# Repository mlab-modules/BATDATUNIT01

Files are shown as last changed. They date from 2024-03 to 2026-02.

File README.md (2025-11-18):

# BATDATUNIT01 - Power and Data Storage Module

The BATDATUNIT01 is power and data storage module incorporating an ATmea1284p microcontroller paired with a five 18650 Li-ion safely rechargable accumulator cells. It is a reliable power source for extended durations, making it an integral component in various detectors or measuring systems.

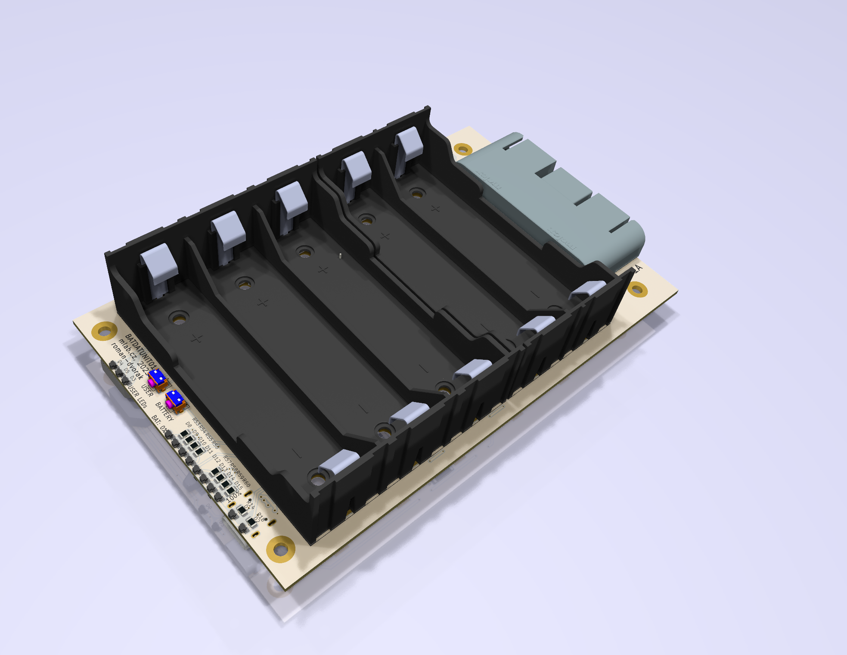
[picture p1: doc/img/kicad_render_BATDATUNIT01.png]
Previw of BATDATUNIT01 PCB


## Features

- **Microcontroller**: [ATmega1284p](https://www.microchip.com/wwwproducts/en/ATmega1284p) provides robust processing capabilities to manage complex tasks efficiently.
- **Battery Pack**: A Set of up to five Li-ion batteries offers substantial power, facilitating long-term operations without frequent recharging.
- **USB-C Charging**: Enables hassle-free charging with a USB-C interface, ensuring the module is readily powered for sustained use.
- **Charging and Monitoring Circuits**: The [BQ25628E](https://www.ti.com/product/BQ25628) circuit oversees the charging, while the [BQ34Z100](https://www.ti.com/product/BQ34Z100) gauge monitors the battery state for optimal energy management.

## Applications

The BATDATUNIT01 is designed for versatility:

- As a **power module for semiconductor particle detectors** like the [AIRDOS04](https://github.com/UniversalScientificTechnologies/AIRDOS04), it ensures uninterrupted data acquisition in environmental monitoring.
- It can be integrated into **remote sensing stations**, providing consistent power and data logging capabilities for long-term ecological studies.
- In **automated weather stations**, the module's resilience and sensor suite offers valuable insights into meteorological conditions.
- The module can be deployed in **mobile robotics** for energy supply and environmental data collection, aiding navigation and decision-making processes.
- It is also ideal for **educational purposes**, as a hands-on tool to teach about energy management, data acquisition, and sensor integration.

The robust design and connectivity options make the BATDATUNIT01 a dependable choice for powering and managing data across many scientific applications.

For more detailed information on interfacing and protocols, please refer to the [ATmea1284p datasheet](https://ww1.microchip.com/downloads/en/DeviceDoc/doc8059.pdf) and the communication standards for [UART](https://en.wikipedia.org/wiki/Universal_asynchronous_receiver-transmitter), [I2C](https://www.i2c-bus.org/), [SPI](https://en.wikipedia.org/wiki/Serial_Peripheral_Interface), and [GPIO](https://en.wikipedia.org/wiki/General-purpose_input/output).

## Design

Designed for convenience, the module allows for fast detachment from the measuring part without tools, streamlining the replacement process. Data can be downloaded during battery charging thanks to onboard memory.

BATDATAUNIT01 top view

BATDATAUNIT01 bottom view

## Schematics



### Internal structure

```mermaid

    flowchart TD

    subgraph a[User interfaceI]
        USB[[USB-C\nData + power]]
        UI1([User interface \n Button + battery indicator])
        UI2([User interface \n Button + 3x LED])
    
    end

    USB --USB --> USW

    FTDI -- I2C --> I2CSW
    FTDI -- UART <--> MCU
    MCU -- I2C --> I2CSW[I2C mux]
    MCU[Microcontroller]
    MCU --SPI <--> SDW
    MCU --> SDW

    subgraph one[Memory interface]
    SDR[SD card] <--> SDI
    SDI[SD card interface] -- USB <--> USW
    USW[USB-SWITCH]
    SDW[SD card \n SPI-SWITCH] <--> SDI
    end

    subgraph three[Digital part ]
    USW -- USB <--> FTDI[FTDI\nI2C + UART]

    I2CSW --I2C--> HYG[Hygrometer]
    I2CSW --I2C--> ALT[Pressure sensor]

    I2CSW -- I2C --> I2Cen

    end

    I2CSW --I2C--> GAUGE
    I2CSW --I2C--> charger

    GAUGE --> UI1
    MCU --> UI2

    GAUGE --> PWR3v3
    GAUGE --> PWR3v3E
    GAUGE --> PWR5vE
    
    USB -- Power --> charger

    subgraph two[POWER sources]
    PWR3v3[Power supply\nfor internal 3.3V]
    PWR3v3E[Power supply\nfor detector 3.3V]
    PWR5vE[Power supply\nfor detector 5V]
    
    charger --> GAUGE[Accumulators gauge]
    GAUGE <==> LIION[(5x Li-ion cells)]
    end
    PWR3v3 --> MCU

    PWR3v3E --> DI
    PWR5vE --> DI

    I2Cen[I2C switch] -- I2C --> DI
    DI[[Detector interface]] == GPIO, SPI <==> MCU

```

## Connectivity

A durable Molex connector brings together data and detection with impressive mechanical resilience. It hosts UART, I2C, SPI buses, and extra GPIO signals, providing extensive interfacing options with various systems. The complementary module to the interface connector is [BATDATSOCKET01](https://github.com/mlab-modules/BATDATSOCKET01).

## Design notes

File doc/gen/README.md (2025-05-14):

# PCB

Board size: 136.15x85.85 mm (5.36x3.38 inches)

- This is the size of the rectangle that contains the board
- Thickness: 1.6 mm (63 mils)
- Material: FR4
- Finish: None
- Layers: 2
- Copper thickness: 35 µm

Solder mask: TOP / BOTTOM

- Color: Green

Silk screen: TOP / BOTTOM

- Color: White

Stackup:

| Name | Type | Color | Thickness [µm]| Material | Er | Loss tan |
|---|---|---|---|---|---|---|
| F.SilkS | Top Silk Screen | White | | | | |
| F.Paste | Top Solder Paste | | | | | |
| F.Mask | Top Solder Mask | Green | 10 | | | |
| F.Cu | copper | | 35 | | | |
| dielectric 1 | core | FR4 natural | 1510 | FR4 | 4.5 | 0.020 |
| B.Cu | copper | | 35 | | | |
| B.Mask | Bottom Solder Mask | Green | 10 | | | |
| B.Paste | Bottom Solder Paste  | | | | | |
| B.SilkS | Bottom Silk Screen | White | | | | |

# Important sizes

Clearance: 0.2 mm (8 mils)

Track width: 0.2 mm (8 mils)

- By design rules: 0.0 mm (0 mils)

Drill: 0.4 mm (16 mils)

- Vias: 0.4 mm (16 mils) [Design: 0.35 mm (14 mils)]
- Pads: 0.6 mm (24 mils)
- The above values are real drill sizes, they add 0.1 mm (4 mils) to plated holes (PTH)

Via: 0.5/0.3 mm (20/12 mils)

- By design rules: 0.5/0.25 mm (20/10 mils)
- Micro via: yes [0.2/0.1 mm (8/4 mils)]
- Buried/blind via: yes
- Total: 415 (thru: 415 buried/blind: 0 micro: 0)

Outer Annular Ring: 0.05 mm (2 mils)

- By design rules: 0.05 mm (2 mils)

Eurocircuits class: 6D
- Using min drill 0.25 mm for an OAR of 0.13 mm

# General stats

Components count: (SMD/THT)

- Top: 27/7 (SMD + THT)
- Bottom: 173/3 (SMD + THT)

Defined tracks:

- 0.2 mm (8 mils)
- 0.3 mm (12 mils)
- 0.4 mm (16 mils)
- 0.5 mm (20 mils)

Used tracks:

- 0.2 mm (8 mils) (136) defined: yes
- 0.25 mm (10 mils) (68) defined: no
- 0.3 mm (12 mils) (1377) defined: yes
- 0.4 mm (16 mils) (136) defined: yes
- 0.5 mm (20 mils) (55) defined: yes
- 0.8 mm (31 mils) (38) defined: no
- 0.9 mm (35 mils) (19) defined: no
- 1.0 mm (39 mils) (31) defined: no
- 1.5 mm (59 mils) (3) defined: no

Defined vias:

- 0.5/0.3 mm (20/12 mils)
- 0.8/0.4 mm (31/16 mils)

Used vias:

- 0.5/0.3 mm (20/12 mils) (Count: 257, Aspect: 3.2 A) defined: yes
- 0.8/0.4 mm (31/16 mils) (Count: 158, Aspect: 2.0 A) defined: yes

Holes (excluding vias):

- 0.65 mm (26 mils) (2)
- 0.75 mm (30 mils) (30)
- 1.02 mm (40 mils) (40)
- 1.6 mm (63 mils) (10)
- 3.0 mm (118 mils) (4)
- 3.2 mm (126 mils) (12)

Oval holes:

- 0.5x0.9 mm (20x35 mils) (4)
- 0.6x1.4 mm (24x55 mils) (2)
- 0.6x1.7 mm (24x67 mils) (2)

Drill tools (including vias and computing adjusts and rounding):

- 0.4 mm (16 mils) (257)
- 0.5 mm (20 mils) (158)
- 0.6 mm (24 mils) (4)
- 0.65 mm (26 mils) (2)
- 0.7 mm (28 mils) (4)
- 0.85 mm (33 mils) (30)
- 1.1 mm (43 mils) (40)
- 1.7 mm (67 mils) (10)
- 3.1 mm (122 mils) (4)
- 3.2 mm (126 mils) (12)

Solder paste stats:

Using a paste with 87.75 % alloy, that has an specific gravity for the alloy of 7.4 g/cm³
and 1.0 g/cm³ for the flux. This paste has an specific gravity of  4.15 g/cm³.

The stencil thickness is  0.12 mm.

| Side | Pads with paste | Area [mm²] | Paste [g] |
|---|---|---|---|
| Top | 60 | 68.31 | 0.34 |
| Bottom | 640 | 831.67 | 4.14 |
| Total  | 700 | 899.98 | 4.48 |

Note: this is just an approximation to the theoretical value. Margins of the solder mask and waste aren't computed.

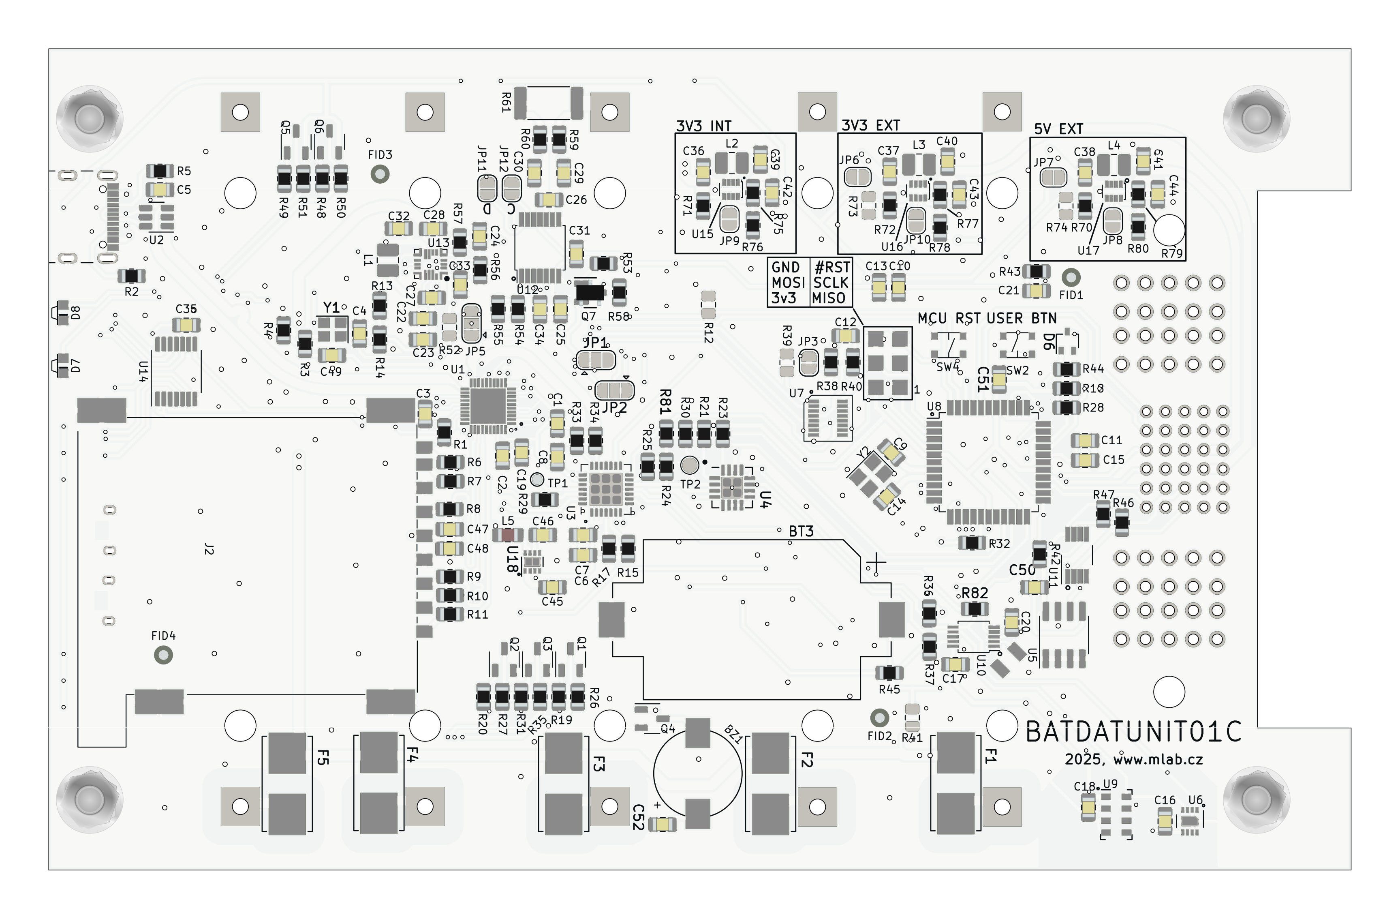
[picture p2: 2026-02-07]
doc/gen/img/BATDATUNIT01-bottom.png

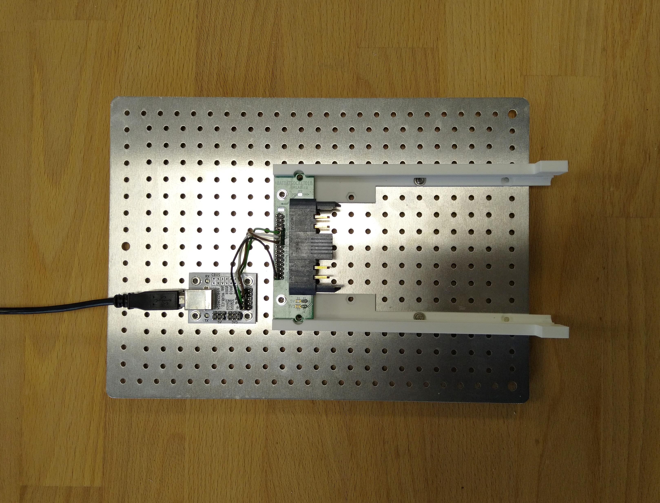
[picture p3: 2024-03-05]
doc/img/BATDATUNIT01_programming_device.jpg

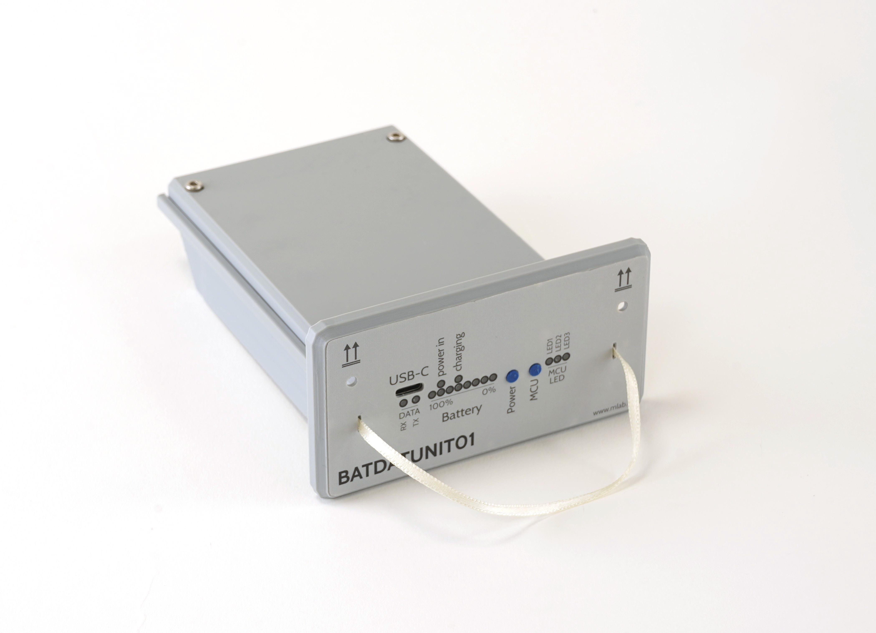
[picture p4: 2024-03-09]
doc/img/BATDATUNIT01.jpg

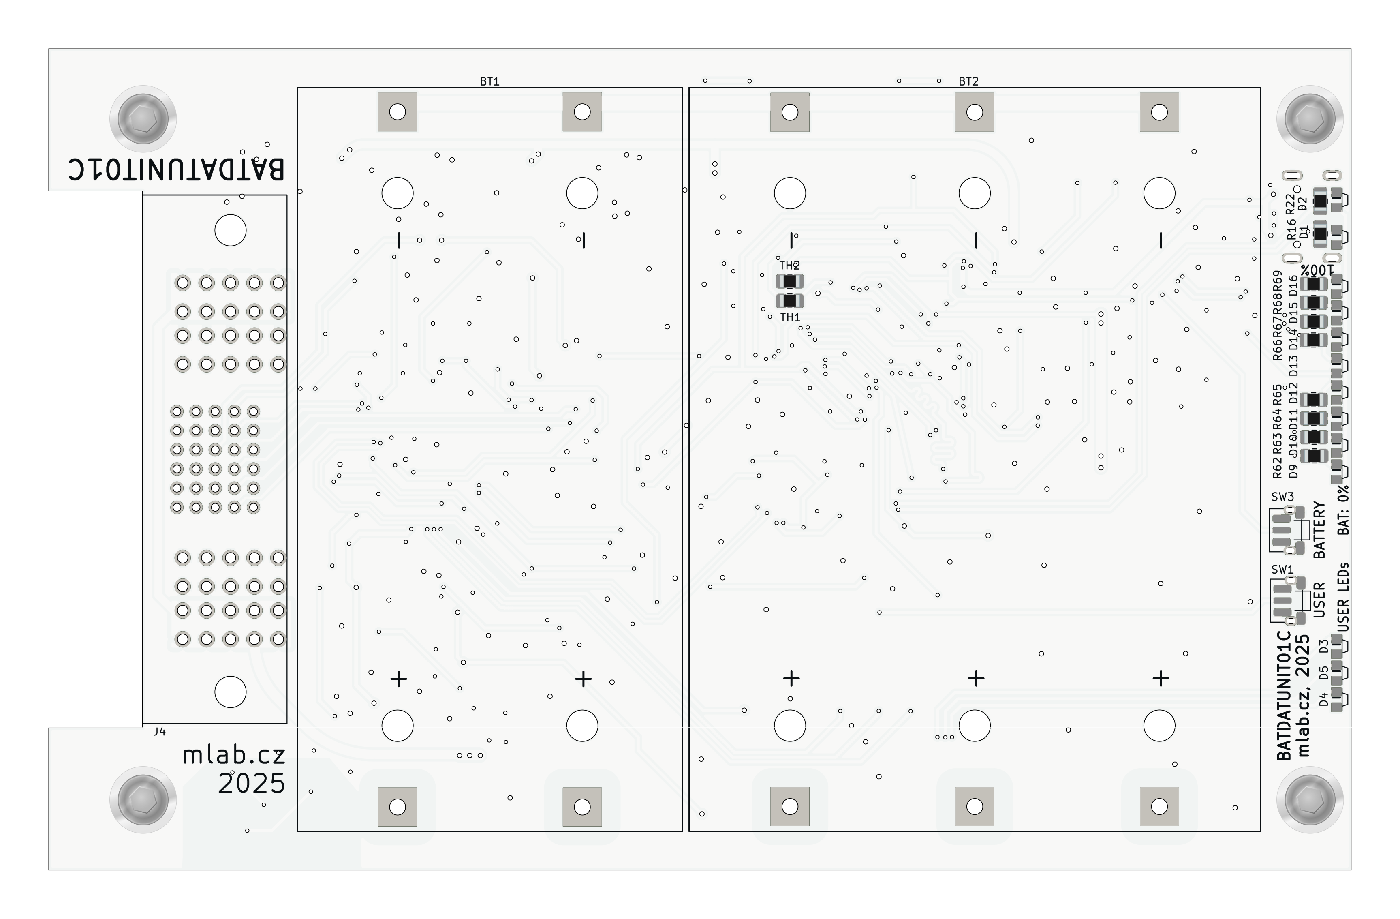
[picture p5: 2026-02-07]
doc/gen/img/BATDATUNIT01-top.png

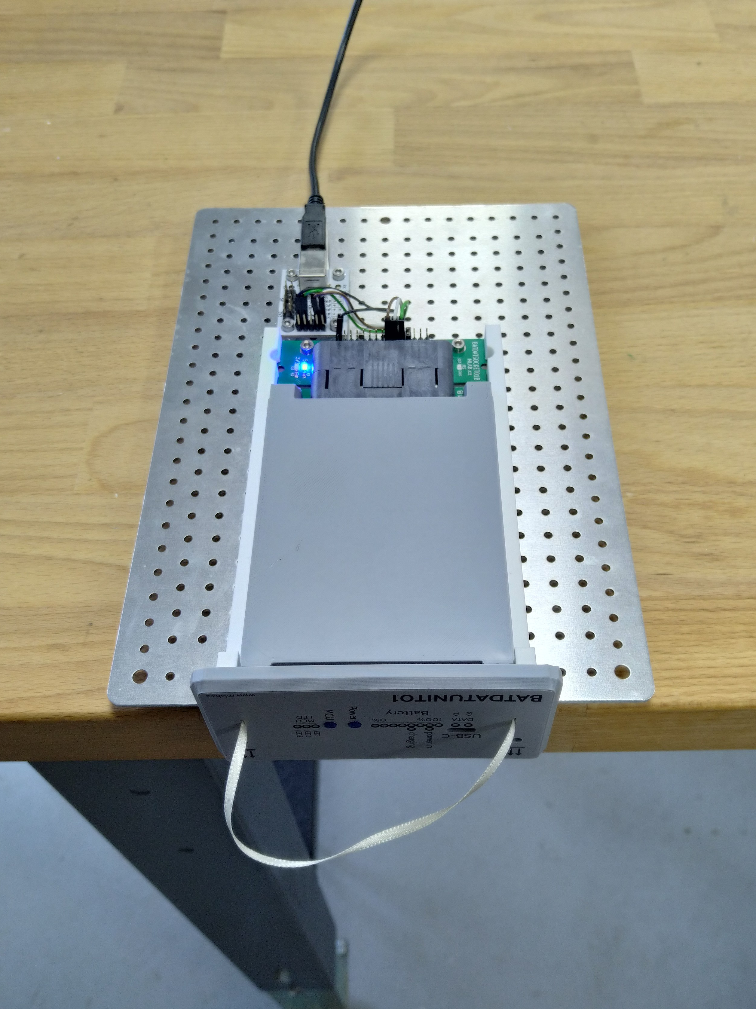
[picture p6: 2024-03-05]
doc/img/BATDATUNIT01_programming.jpg

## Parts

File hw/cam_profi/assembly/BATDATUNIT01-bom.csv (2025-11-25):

Component | Description | Part | References | Value | Footprint | Quantity Per PCB | Datasheet | ust_id | mfpn | mpn | sim.device | sim.type | sim.pins | height | i2c | manufacturer_name | manufacturer_part_number | mouser part number | mouser price/stock | arrow part number | arrow price/stock | lcsc
1 | Single-cell battery | 2xBATT | BT1 | BATT | BAT_BK-18650-PC4 | 1 | ~ | 5c70984412875079b91f87e9
2 | Single-cell battery | 3xBATT | BT2 | BATT | BAT_BK-18650-PC6 | 1 | ~ | 63567f66c8e7b5bbef872ce1
3 | Single-cell battery | Battery_Cell | BT3 | CR2032 | BatteryHolder_Keystone_1060_1x2032 | 1 | ~ | 68249eacee7fc534862c6977
4 | Buzzer, polarized | Buzzer | BZ1 | LET9032ES-03L | MagneticBuzzer_LET9032ES-03L-2.7-16-R | 1 | https://www.cre-soundbuzzer.com/datasheet/LET9032ES-03L-2.7-16-R.pdf | 5fa0f13812875025b3977890
5 | Unpolarized capacitor, small symbol | C_Small | C9C14 | 15p | C_0805_2012Metric | 2 | ~ | 5c70984712875079b91f8b32
6 | Unpolarized capacitor, small symbol | C_Small | C5C46 | 1n | C_0805_2012Metric | 2 | ~ | 5c70984712875079b91f8b45 | C0805 1u | C0805 1u
7 | Unpolarized capacitor, small symbol | C_Small | C34 | 3n3 | C_0805_2012Metric | 1 | ~ | 5c70984712875079b91f8b47
8 | Unpolarized capacitor, small symbol | C_Small | C27 | 47n | C_0805_2012Metric | 1 | ~ | 65482046462c6d9e72056b98
9 | Unpolarized capacitor, small symbol | C_Small | C1C2C3C4C6C8C10C13C15C16C17C18C20C23C25C26C29C30C35C48C49C50C51C52 | 100n | C_0805_2012Metric | 24 | ~ | 5c70984712875079b91f8b4c
10 | Unpolarized capacitor, small symbol | C_Small | C19C24C31C45 | 1u | C_0805_2012Metric | 4 | ~ | 5c70984712875079b91f8b50
11 | Unpolarized capacitor, small symbol | C_Small | C7C12C33 | 4u7 | C_0805_2012Metric | 3 | ~ | 5c70984712875079b91f8b52
12 | Unpolarized capacitor, small symbol | C_Small | C11C22C28C42C43C44C47 | 10u | C_0805_2012Metric | 7 | ~ | 5c70984712875079b91f8b53
13 | Unpolarized capacitor, small symbol | C_Small | C21C32C36C37C38 | 22u | C_0805_2012Metric | 5 | ~ | 650b58f1462c6d9e7205463b
14 | Unpolarized capacitor, small symbol | C_Small | C39C40C41 | 47u | C_0805_2012Metric | 3 | ~ | 5c70984812875079b91f8bbf
15 | 100V, 0.175A, High-speed Switching Diode, SOT-323 | BAS16W | D6 | BAS16W | SOT-323_SC-70 | 1 | https://assets.nexperia.com/documents/data-sheet/BAS16_SER.pdf | 5c70984512875079b91f88af
16 | Light emitting diode, small symbol | LED_Small | D3D8D13D14D15D16 | GREEN | SMD_LED_RIGHT_KINGBRIGHT_1605 | 6 | ~ | 65481f0c462c6d9e72056b3d
17 | Light emitting diode | LED | D2 | GREEN | SMD_LED_RIGHT_KINGBRIGHT_1605 | 1 | https://cz.mouser.com/datasheet/2/216/APA1606SGC-76546.pdf | 65481f0c462c6d9e72056b3d
18 | Light emitting diode, small symbol | LED_Small | D4D7D11D12 | ORANGE | SMD_LED_RIGHT_KINGBRIGHT_1605 | 4 | ~ | 65481fdd462c6d9e72056b6a
19 | Light emitting diode | LED | D1 | RED | SMD_LED_RIGHT_KINGBRIGHT_1605 | 1 | https://cz.mouser.com/datasheet/2/216/APA1606SURCK-63848.pdf | 65481f96462c6d9e72056b54
20 | Light emitting diode, small symbol | LED_Small | D5D9D10 | RED | SMD_LED_RIGHT_KINGBRIGHT_1605 | 3 | ~ | 65481f96462c6d9e72056b54
21 | Fuse | Fuse | F1F2F3F4F5 | Fuse | Fuseholder_Littelfuse_Nano2_154x | 5 | https://cz.mouser.com/datasheet/2/240/media-3321028.pdf | 5c70984512875079b91f88d8
22 |  | MOLEX_46436-9327 | J4 | 46436-9327 | MOLEX_46436-9327 | 1 |  | 65481d4a462c6d9e72056b06
23 | 2x03 2.54 mm pitch header | HEADER_2x03 | J3 | HEADER_2x03 | SMD_2x03 | 1 |  | x
24 |  | SD_Card-FPS009-4200-0 | J2 | SD_Card-FPS009-4200-0 | FPS009-4200-0 | 1 |  | 5cdd24d5128750448edda353
25 | USB 2.0-only Type-C Receptacle connector | USBC_USB4105-GF-A | J1 | USBC_USB4105-GF-A | USBC GCT_USB4105-GF-A | 1 |  | 5fa0f94612875025b397795e | USB4105-GF-A | USB4105-GF-A
26 | Jumper, 2-pole, open | Jumper_2_Open | JP6JP7JP8JP9JP10JP11JP12 | Jumper_2_Open | SolderJumper-2_P1.3mm_Open_RoundedPad1.0x1.5mm | 7 | ~ | x
27 | Inductor | L | L5 | 100uH | L_0805_2012Metric_Pad1.15x1.40mm_HandSolder | 1 | ~ | 626fd6fcdc56076e9a222966
28 | Inductor | L | L1L2L3L4 | 1uH - DFE252012P-1R0M=P2 | L_1008_2520Metric | 4 | ~ | 650b5977462c6d9e72054656
29 | PNP transistor, base/emitter/collector | Q_PNP_BEC | Q5Q6 | BC807-25 | SOT-23-3 | 2 | ~ | 5c70984712875079b91f8aeb |  |  | NPN | GUMMELPOON | 1=C 2=B 3=E
30 | NPN transistor, base/emitter/collector | Q_NPN_BEC | Q1Q2Q3Q4 | BC817-25 | SOT-23-3 | 4 | ~ | 5c70984712875079b91f8aea |  |  | NPN | GUMMELPOON | 1=C 2=B 3=E
31 | P-MOSFET transistor, gate/source/drain | Q_PMOS_GSD | Q7 | BSS83P | SOT-23 | 1 | ~ | 5c70984712875079b91f8ae6
32 | Resistor, small symbol | R_Small | R33R34 | 33R | R_0805_2012Metric | 2 | ~ | 5c70984512875079b91f8970
33 | Resistor, small symbol | R_Small | R22R26R51R66R67R68R69 | 68R | R_0805_2012Metric | 7 | ~ | 5c70984512875079b91f8975
34 |  | R-device-DATALOGGER01A-rescue-CCP2019V01A-rescue-SPACEDOS01A_PCB01A-rescue-SPACEDOS01B_PCB01A-rescue | R6R7R8R9R10R11R38R82 | 100R | R_0805_2012Metric | 8 |  | 5c70984512875079b91f8977
35 | Resistor, small symbol | R_Small | R59R60 | 100R | R_0805_2012Metric | 2 | ~ | 5c70984512875079b91f8977
36 | Resistor, small symbol | R_Small | R16R27R35R50R54R62R63R64R65 | 270R | R_0805_2012Metric | 9 | ~ | 5c70984512875079b91f8983
37 | Resistor, small symbol | R_Small | R53 | 510R | R_0805_2012Metric | 1 | ~ | 5c70984512875079b91f8988
38 | Resistor, small symbol | R_Small | R15R17R19R20R31R32R48R49R55 | 1k | R_0805_2012Metric | 9 | ~ | 5c70984512875079b91f898c
39 | Resistor, small symbol | R_Small | R56 | 2k4 | R_0805_2012Metric | 1 | ~ | 5c70984612875079b91f8991
40 | Resistor, small symbol | R_Small | R2R4R5R29R57 | 5k1 | R_0805_2012Metric | 5 | ~ | 5fa0fc3e12875025b3977997
41 | Resistor, small symbol | R_Small | R1 | 6.19k | R_0805_2012Metric | 1 | ~ | 6548142e462c6d9e72056976
42 | Resistor, small symbol | R_Small | R3R18R21R23R24R25R28R30R36R37R40R42R44R46R47R70R72R81 | 10k | R_0805_2012Metric | 18 | ~ | 5c70984612875079b91f899f
43 | Resistor, small symbol | R_Small | R14 | 25k5 | R_0805_2012Metric | 1 | ~ | 5c70984712875079b91f8a88
44 | Resistor, small symbol | R_Small | R58 | 33k | R_0805_2012Metric | 1 | ~ | 5c70984712875079b91f8a8a
45 | Resistor, small symbol | R_Small | R13 | 68k | R_0805_2012Metric | 1 | ~ | 5c70984712875079b91f8a91
46 | Resistor, small symbol | R_Small | R76R78R80 | 91k | R_0805_2012Metric | 3 | ~ | 5c70984712875079b91f8a95
47 | Resistor, small symbol | R_Small | R43 | 270k | R_0805_2012Metric | 1 | ~ | 5c70984712875079b91f8aa0
48 | Resistor, small symbol | R_Small | R75R77 | 511k | R_0805_2012Metric | 2 | ~ | 650b5a43462c6d9e7205468e
49 | Resistor, small symbol | R_Small | R79 | 806k | R_0805_2012Metric | 1 | ~ | 650b5abb462c6d9e720546b8
50 | Resistor, small symbol | R_Small | R61 | 0R01 75PPM | R_2512_6332Metric | 1 | ~ | 5c70984712875079b91f8abf
51 | Push button switch, generic, two pins | SW_Push | SW2SW4 | KMT031 | KMT031 NGJ LHS C&K | 2 | ~ | 612515a61287500165a9771d
52 | Push button switch, generic, two pins | SW_Push_shield | SW1SW3 | SKRTLAE010 | SKRT | 2 | ~ | 65481517462c6d9e720569b4
53 | Temperature dependent resistor | Thermistor | TH1 | 10k NTC | R_0805_2012Metric | 1 | ~ | 5c70984712875079b91f8ac5
54 | Temperature dependent resistor, negative temperature coefficient | Thermistor_NTC | TH2 | 10k NTC | R_0805_2012Metric | 1 | ~ | 5c70984712875079b91f8ac5
55 | I2C Serial EEPROM, 64Kb (8192x8) with Unique Serial Number, SO8 | AT24CS64-SSHM | U5 | AT24CS64-SSHM | SOIC-8_3.9x4.9mm_P1.27mm | 1 | http://ww1.microchip.com/downloads/en/DeviceDoc/Atmel-8870-SEEPROM-AT24CS64-Datasheet.pdf | 5c70984712875079b91f8b99 |  |  |  |  |  | 1.5
56 | 20MHz, 128kB Flash, 16kB SRAM, 4kB EEPROM, JTAG, TQFP-44 | ATmega1284P-A | U8 | ATMEGA1284P-AU | TQFP-44_10x10mm_P0.8mm | 1 | http://www.atmel.com/Images/Atmel-8272-8-bit-AVR-microcontroller-ATmega164A_PA-324A_PA-644A_PA-1284_P_datasheet.pdf | 5c70984412875079b91f888e |  |  |  |  |  | 1.1
57 | BQ25628E I2C Controlled 1-Cell, 2-A, Maximum 18-V Input, Buck Battery Charger with NVDC Power Path Management | BQ25628E | U13 | BQ25628E | Texas_S-WQFN-HR-18 | 1 | https://www.ti.com/lit/ds/symlink/bq25628e.pdf | 65481a71462c6d9e72056aa4 |  |  |  |  |  |  | 0x6B
58 |  | BQ34Z100 | U12 | BQ34Z100 | TSSOP-14_4.4x5mm_Pitch0.65mm | 1 | https://www.ti.com/lit/ds/symlink/bq34z100-g1.pdf | 5c70984612875079b91f89c3 |  |  |  |  |  | 1,2 | 0xAA
59 | USB HID to UART/I2C Bridge WQFN-28 Tray FTDI Chip FT260Q-T, USB Controller, 3.4MBps, HID, I2C, UART, USB 2.0, 1.8 V, 2.5 V, 3.3 V, 5 V, 28-Pin WQFN | FT260Q-T | U3 | FT260Q-T | QFN-28-1EP_5x5mm_P0.5mm_EP3.35x3.35mm | 1 | http://www.ftdichip.com/Support/Documents/DataSheets/ICs/DS_FT260.pdf | 65481702462c6d9e72056a21 |  |  |  |  |  | 0.8 |  | FTDI Chip | FT260Q-T | 895-FT260Q-T | https://www.mouser.co.uk/ProductDetail/FTDI/FT260Q-T?qs=b3QwWlrdtstFEkgcxHO4EA%3D%3D | FT260Q-T | https://www.arrow.com/en/products/ft260q-t/ftdi-chip?region=nac
60 | Hi-Speed USB-to-SD Card Readers with Bypass | MAX14502AETL+ | U1 | MAX14502AETL+ | QFN40P500X500X80-41N | 1 | https://datasheet.octopart.com/MAX14502AETL%2B-Dallas-Semiconductor-datasheet-13718882.pdf | 6548165f462c6d9e720569f7 |  |  |  |  |  | 0.8 | 0x71 | Analog Devices | MAX14502AETL+
61 | Sensor Pressure 1.2bar Barometric SMD MS561101BA03-50, Barometric Pressure Sensor, 1200mbar 0 3.6 V Output, 8-Pin QFN | MS561101BA03-50 | U9 | MS561101BA03-50 | LGA-8_3x5mm_P1.25mm | 1 | https://cz.mouser.com/datasheet/2/418/6/ENG_DS_MS5611_01BA03_B3-1134567.pdf | 650b36b0462c6d9e720543f4 |  |  |  |  |  | 1 | 0x76 | TE Connectivity | MS561101BA03-50 | 824-MS561101BA03-50 | https://www.mouser.co.uk/ProductDetail/Measurement-Specialties/MS561101BA03-50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
62 | I/O Controller Interface IC 2-to-1 I2C-bus master selector | PCA9541ABS_03,118 | U4 | PCA9541ABS/01 | QFN-16-1EP_4x4mm_P0.65mm_EP2.15x2.15mm | 1 | http://www.nxp.com/docs/en/data-sheet/PCA9541A.pdf | 65481909462c6d9e72056a4a |  |  |  |  |  | 1 | 0x70 | NXP | PCA9541ABS/03,118 | 771-PCA9541ABS03,118 | https://www.mouser.co.uk/ProductDetail/NXP-Semiconductors/PCA9541ABS-03118?qs=zgUyOPfUqsKSEeCPg1WHUw%3D%3D
63 | RTC | PCF85263A | U10 | PCF85263A | TSSOP-10_3x3mm_P0.5mm | 1 | https://www.nxp.com/docs/en/data-sheet/PCF85263A.pdf | 5c70984612875079b91f8a0c |  |  |  |  |  | 1.1 | 0x
64 | I²C humidity and temperature sensor, ±1.5%RH, ±0.1°C, DFN-8 | SHT35-DIS | U6 | SHT31-DIS | Sensirion_DFN-8-1EP_2.5x2.5mm_P0.5mm_EP1.1x1.7mm | 1 | https://sensirion.com/media/documents/213E6A3B/63A5A569/Datasheet_SHT3x_DIS.pdf | 5c70984612875079b91f89e4 |  |  |  |  |  | 0.9 | 0x44
65 |  | SN74HC164D | U14 | SN74HC164P | TSSOP-14_4.4x5mm_P0.65mm | 1 | https://www.ti.com/lit/ds/symlink/sn74hc164.pdf | 6559399f95a79cc5ac40a0a6
66 |  | TCA4307 | U11 | TCA4307 | VSSOP-8_3.0x3.0mm_P0.65mm | 1 | https://www.ti.com/lit/ds/symlink/tca4307.pdf?ts=1617607418171 | 6087a3f3128750769ee58f03
67 | Analogue Switch ICs Low-capacitance, 2:1 (SPDT) 4-channel, powered-off protection switch with 1.8-V logic 16-SOT-23-THN -40 to 125 | TMUX1574DYYR | U7 | TMUX1574DYYR | SOT-23-16 THIN | 1 | https://www.ti.com/lit/gpn/TMUX1574 | 65481983462c6d9e72056a6d |  |  |  |  |  | 1.1 |  | Texas Instruments | TMUX1574DYYR | 595-TMUX1574DYYR | https://www.mouser.co.uk/ProductDetail/Texas-Instruments/TMUX1574DYYR?qs=B6kkDfuK7%2FDgs0e8M6dtlw%3D%3D | TMUX1574DYYR | https://www.arrow.com/en/products/tmux1574dyyr/texas-instruments?region=nac
68 |  | TPS22965-Q1-MLAB_IO | U18 | TPS22965-Q1 | WSON-8-1EP_2x2mm_P0.5mm_EP0.9x1.6mm | 1 | https://www.ti.com/lit/ds/symlink/tps22965-q1.pdf | 5c70984712875079b91f8b78
69 | Switching Voltage Regulators 1.5-A output current, high power density buck-boost converter | TPS631000DRLR | U15U16U17 | TPS631000DRLR | SOT-583-8 | 3 | https://www.ti.com/lit/ds/symlink/tps631000.pdf?ts=1652152702265 | 63de5ae4ae0b2d5aa05e2714 |  |  |  |  |  | 0.5 |  | Texas Instruments | TPS631000DRLR | 595-TPS631000DRLR | https://www.mouser.co.uk/ProductDetail/Texas-Instruments/TPS631000DRLR?qs=rSMjJ%252B1ewcRYwoN2deTeNA%3D%3D
70 | Very low capacitance ESD protection diode, 2 data-line, SOT-23-6 | USBLC6-2SC6 | U2 | USBLC6-2SC6 | SOT-23-6 | 1 | https://www.st.com/resource/en/datasheet/usblc6-2.pdf | 5e82e0691287502a334a778c |  |  |  |  |  |  |  |  |  |  |  |  |  | C7519
71 | Crystal Clock Oscillator, | CXO_DIP8 | Y1 | 19.2 MHz | Crystal_SMD_2520-4Pin_2.5x2.0mm | 1 |  | 67f16090ee7fc534862c5860
72 | Four pin crystal, GND on pins 2 and 4, small symbol | Crystal_GND24_Small | Y2 | 8 MHz | Crystal_SMD_3225-4Pin_3.2x2.5mm | 1 | ~ | 65481c4c462c6d9e72056ac8
73 |  | Crystal-device-DATALOGGER01A-rescue-CCP2019V01A-rescue | Y3 | ABS07-120-32.768KHZ-T | ABS07 | 1 |  | 5c70984712875079b91f8b1b

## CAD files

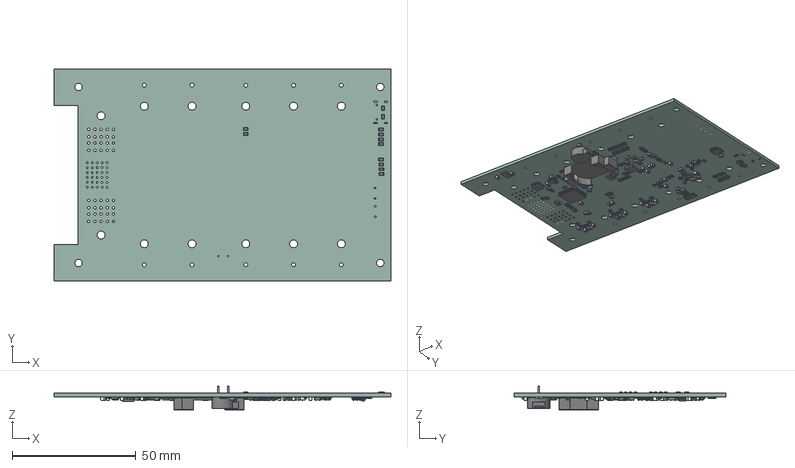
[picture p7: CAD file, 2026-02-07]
doc/gen/BATDATUNIT01.step
136.2 x 85.9 x 9.68 mm
R_0805_2012Metric x 77
LGA-8_3x5mm_P1.25mm
C_0805_2012Metric x 52
SOT-23-3 x 4
SOT-23 x 7
L_1008_2520Metric x 4
SOT-583-8 x 3
SOT-23-6
R_2512_6332Metric
BatteryHolder_Keystone_1060_1x2032
QFN-16-1EP_4x4mm_P0.65mm_EP2.15x2.15mm
L_0805_2012Metric
Crystal_SMD_3225-4Pin_3.2x2.5mm
WSON-8-1EP_2x2mm_P0.5mm_EP0.9x1.6mm
SOIC-8_3.9x4.9mm_P1.27mm
QFN-28-1EP_5x5mm_P0.5mm_EP3.35x3.35mm
SOT-323_SC-70
Texas_S-PWQFN-N20
MagneticBuzzer_CUI_CST-931RP-A
TSSOP-10_3x3mm_P0.5mm
Crystal_SMD_2520-4Pin_2.5x2.0mm
TSSOP-14_4.4x5mm_P0.65mm
TQFP-44_10x10mm_P0.8mm
kibot_usxj4tp5_PCB

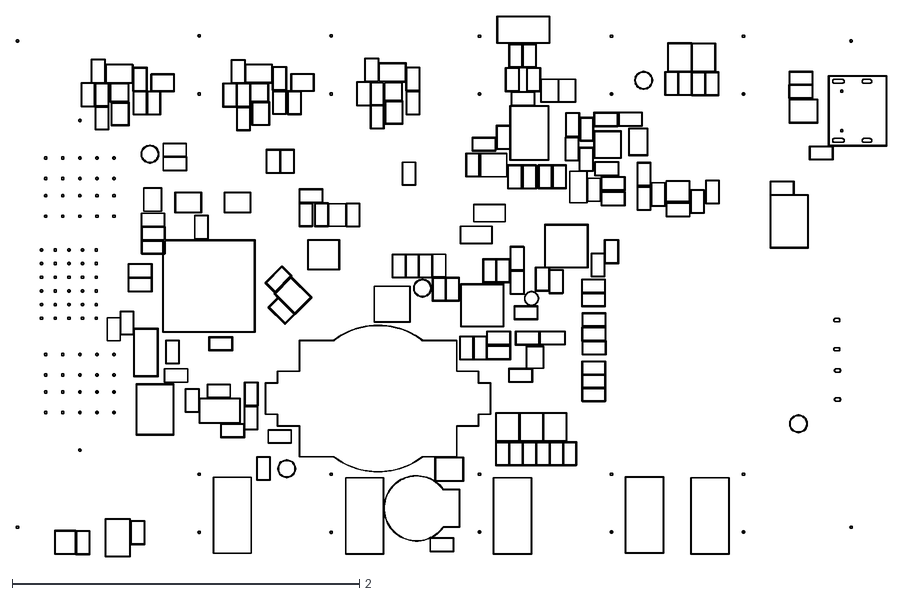
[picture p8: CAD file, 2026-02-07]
doc/gen/dxf/BATDATUNIT01-B_Courtyard.dxf
5.01 x 3.11

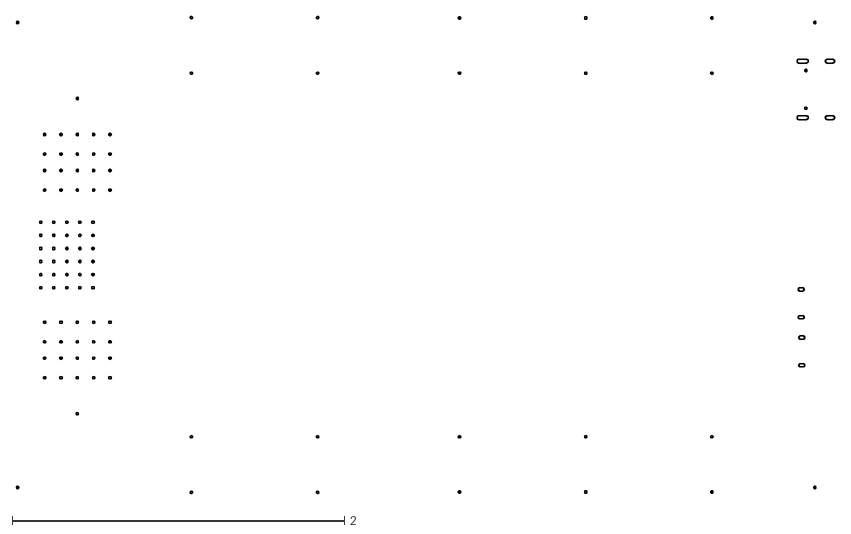
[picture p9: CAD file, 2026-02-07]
doc/gen/dxf/BATDATUNIT01-User_Eco2.dxf
4.93 x 2.87

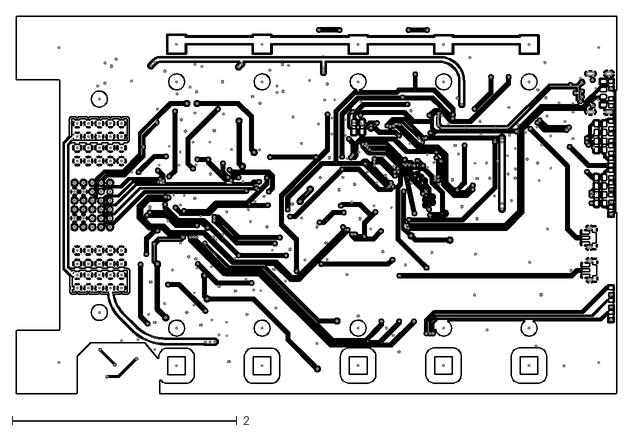
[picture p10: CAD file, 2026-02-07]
doc/gen/dxf/BATDATUNIT01-F_Cu.dxf
5.34 x 3.36

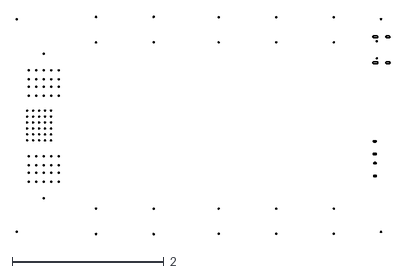
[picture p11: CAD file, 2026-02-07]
doc/gen/dxf/BATDATUNIT01-B_Adhesive.dxf
4.93 x 2.87

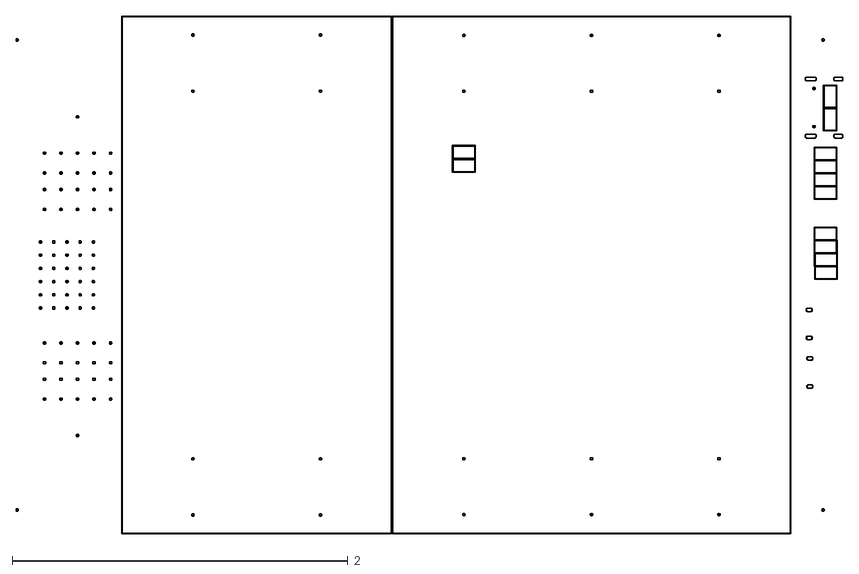
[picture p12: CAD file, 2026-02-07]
doc/gen/dxf/BATDATUNIT01-F_Courtyard.dxf
4.93 x 3.08

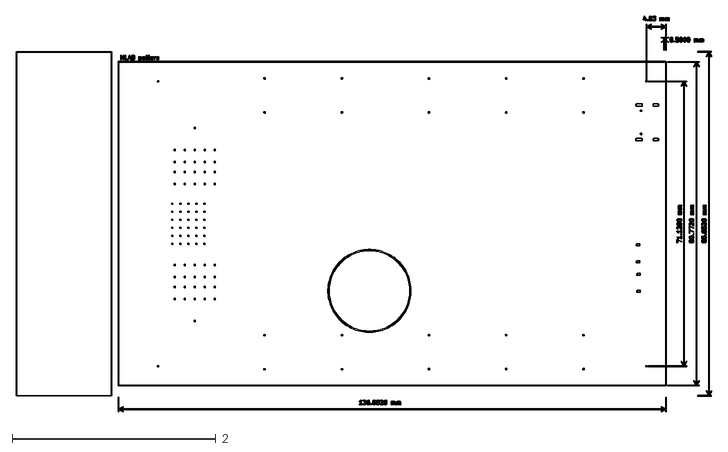
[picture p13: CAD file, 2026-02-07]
doc/gen/dxf/BATDATUNIT01-User_Drawings.dxf
6.83 x 3.89

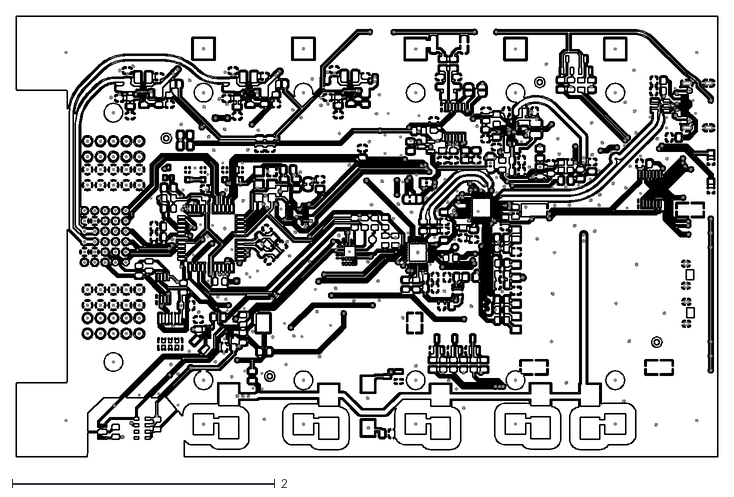
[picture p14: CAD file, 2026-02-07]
doc/gen/dxf/BATDATUNIT01-B_Cu.dxf
5.34 x 3.36

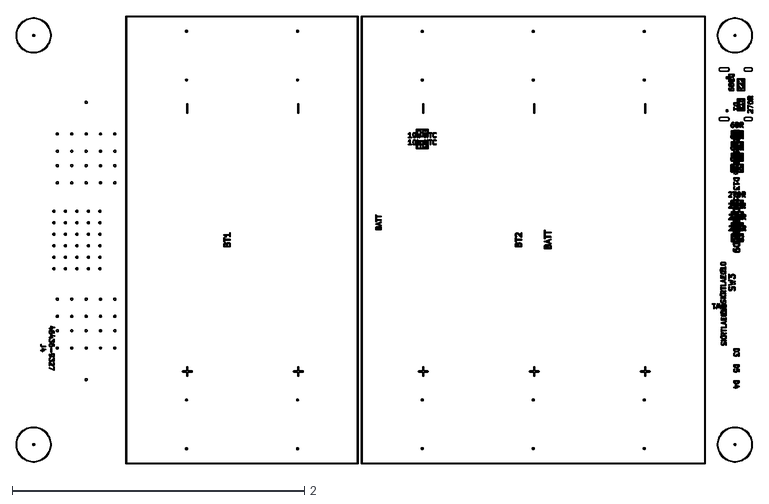
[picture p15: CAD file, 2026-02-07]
doc/gen/dxf/BATDATUNIT01-F_Fab.dxf
5.04 x 3.06

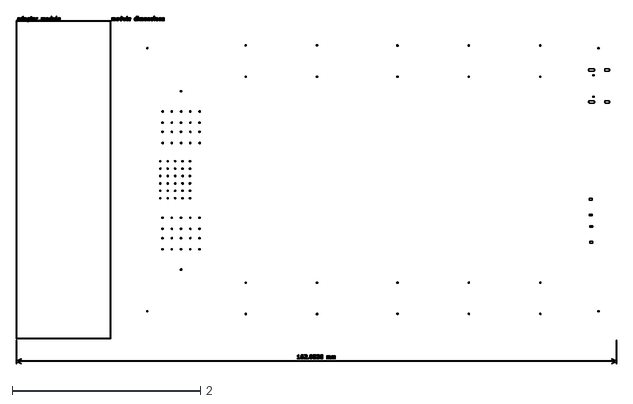
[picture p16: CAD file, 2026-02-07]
doc/gen/dxf/BATDATUNIT01-User_Eco1.dxf
6.39 x 3.69

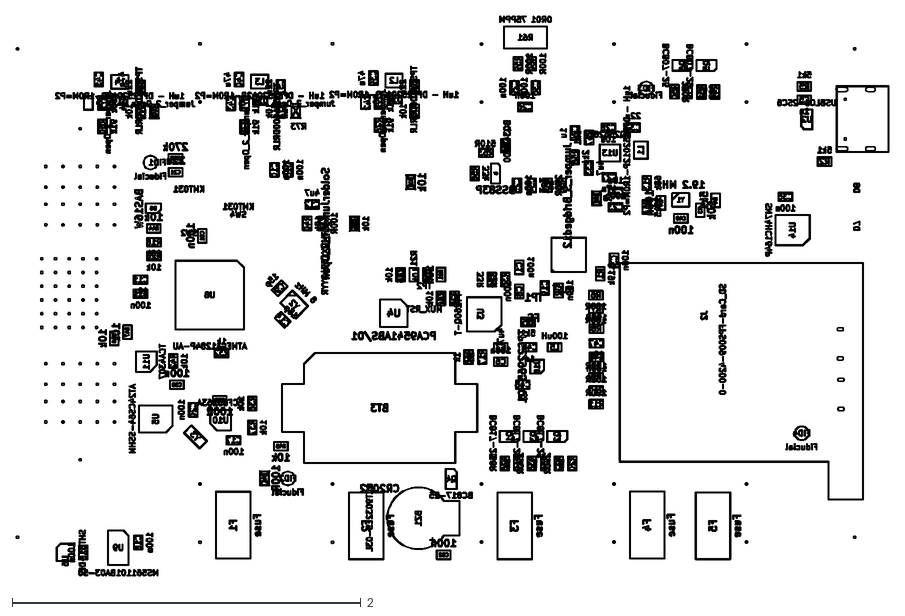
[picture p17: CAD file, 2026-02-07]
doc/gen/dxf/BATDATUNIT01-B_Fab.dxf
5.00 x 3.21

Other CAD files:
doc/gen/dxf/BATDATUNIT01-B_Mask.dxf
doc/gen/dxf/BATDATUNIT01-B_Paste.dxf
doc/gen/dxf/BATDATUNIT01-B_Silkscreen.dxf
doc/gen/dxf/BATDATUNIT01-Edge_Cuts.dxf
doc/gen/dxf/BATDATUNIT01-F_Mask.dxf
doc/gen/dxf/BATDATUNIT01-F_Paste.dxf
doc/gen/dxf/BATDATUNIT01-F_Silkscreen.dxf
doc/gen/dxf/BATDATUNIT01-User_Comments.dxf

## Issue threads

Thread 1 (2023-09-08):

Mechanical design

kaklik, 2023-09-08:
Modul by měl být konstrukčně podobný tomuto modulu: https://github.com/ust-modules/UST5BATT18650V01

To znamená pro připojení článků 18650 využívat pouzdro, ve kterém je možné jednotlivé články vyměnit.

Zásadní rozdíl je v tom, že tento modul má testovat možnost konstrukce vyjímatelného bateriového pouzdra, tudíž by jeho mechanická realizace měla být přibližně takováto:

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

Vodící lišty budou vytištěné vnější stranou na podložku. Tím by měl být tisk hladký a PCB by jezdilo po vrstvách. Zároveň by se zde měla minimálně projevovat křivost tiskáren.
Vodící lišta by se k MLAB desce přišroubovala standardně pomocí šroubů. Na čele vodící lišty by byly M3 otvory se závitovými vložkami, do kterých by se bateriový modul zajistil pomocí šroubů s velkou hlavou.

Na zadní straně lišty by byl vložený PCB s protikusem konektoru. Tento PCB by měl stejný rozměr (šířku) jako PCB bateriového modulu. Modul by byl zajištěn sešroubováním s vodící lištou. Zřejmě z vrchní strany.

Adaptér by obsahoval hřebínky pro univerzální použití (I2C, napájení, atd.) Mechanicky by to bylo spojené přes vodící lištu.

kaklik, 2023-11-27:
Aktuální řešení je pro účely MLABu dostatečné.

Closed 2023-11-27.

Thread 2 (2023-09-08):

Interconnection connectors

kaklik, 2023-09-08:
## Propojení adaptéru a akumulátorového modulu
Konektor musí být dostatečně robustní, aby byl odolný hrubému zacházení a aby byl odolný možným vibracím. Konektor tedy bude zřejmě fyzicky relativně velký.

Konektor musí obsahovat výkonové napájení a datové signály pro budoucí plán akumulátoru s integrovaným procesorem. Tj, že měřící zařízení bude obsluhováno z akumulátoru. Pro spolehlivé zapojení a minimalizaci možnosti zničení konektoru je vhodné, aby konektor měl naváděcí trny a byl zapuštěn pod obrysem pouzdra akumulátoru

### SAMTEC ET60

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

#### 4 piny napájecí, 3x8 signálové
  - https://mou.sr/3OM2pNa
  - https://mou.sr/3QWY5gZ

SAMTEC konektory nejsou moc skladem. Našel jsem tuto variantu, která lze okamžitě koupit a vyhovovala by. Uvádí, že výroba požadovaného konektoru trvá 9 týdnů, netuším cenu oproti konektorům dostupným skladem - bylo by užitečné zjistit předem.

### Molex - ET60

Molex nabízí stejné konektory - vypadá to, že se jedná o úplně stejné konektory vzájemně kompatibilní. Bohužel mají jen verzi s 5 řadami signálních pinů. To se mi nelíbí z důvodu menší rozteče (2mm místo 2.54 mm)  mezi piny (a zřejmě jemnější kontakty).

Tyto konektory jsou skladem ve větším množství v různých variantách. Jsou o dost dražší než SAMTEC konektory.

Varianta: [4 piny napájecí, 5x6 signálové](https://cz.mouser.com/c/connectors/power-connectors/power-to-the-board/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)

## Propojení adaptéru a ostatních MLAB modulů

Pro spojení adaptéru s ostatními MLAB moduly bude potřeba na něm mít hřebínky s těmito signály:

- Napájení 3v3
- Napájení 5V
- I2C
- GPIO univerzální piny (Stavy nabíjecího obvodu atd.)

Dále budou potřeba ještě výkonové vstupní a výstupní svorkovnice
- VBAT+
- VBAT-
- PWR IN + pro nabíjení
- PWR IN -

Closed 2023-11-27.

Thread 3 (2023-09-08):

Requirements on electronics

kaklik, 2023-09-08:
Akumulátorový modul by měl mít vysokou kapacitu to znamená - minimálně Li-ion 1s4p  lépe  Li-ion 1s6p případně Li-ion 1s8p. Na druhou stranu, ale nemůže překročit [přepravní limity](https://www.iata.org/contentassets/6fea26dd84d24b26a7a1fd5788561d6e/passenger-lithium-battery.pdf) Pro splnění limitu ≤ 100 Wh / 2g to znamená  maximálně 7 článků [MJ1](https://eu.nkon.nl/sk/k/Specification%20INR18650MJ1%2022.08.2014.pdf).

Základní vlastnosti:
- Možnost nabíjení přes USB-C (možnost použití PD 2.0 a 3.0 protokolu) při použití s [USBPDSINK01](https://github.com/mlab-modules/USBPDSINK01)
- 4-6 li-ion 18650 článků spojených paralelně přes tavnou pojistku
- Stabilizované výstupní napájení 5V a 3.3V
- Indikace stavu pro uživatele
  - Indikace dostupné energie pomocí LEDbar - po stisknutí tlačítka
  - Indikace stavu dobíjení
- Funkce režimu UPS
  - Možnost nabíjení a zároveň napájení zařízení, permanentní umístění zařízení do místa s nespolehlivým zdrojem napájení. Tohle je potřeba vyzkoumat jak udělat, aby nebyly akumulátory permanentně cyklovány a nebo stále nabity na 4.2V. Je ale možné to nechat na připojeném MCU.

### Nabíjecí obvod
[BQ25628E](https://www.ti.com/lit/ds/symlink/bq25628e.pdf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)

### Měřící obvod
[BQ34Z100](https://www.ti.com/lit/ds/symlink/bq34z100.pdf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)

### Stabilizované výstupní napájení
DC-DC měnič na 3V3/5V [STEPBUBODC01](https://www.mlab.cz/module/STEPBUBODC01/)

kaklik, 2023-11-27:
Tohle je splněno až na ověření funkce režimu UPS, která není kritická.

Closed 2023-11-27.

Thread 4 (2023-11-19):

SDcard layout

kaklik, 2023-11-19:
Aktuální návrh připojení SDkarty:

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

Nesplňuje požadavek z datasheetu:

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

Je potřeba srovnat délky jednotlivých datových cest a zároveň i vyřešit řízenou impedanci USB.

kaklik, 2023-11-28:
Vyřešeno meandrováním cest.

Closed 2023-11-28.

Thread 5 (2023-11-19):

Switch power supply Pull-down resistors value

kaklik, 2023-11-19:
Aktuálně jsou v zapojení pull-down rezistory 1k, které mají zabránit sepnutí měničů v případě, že MCU měniče neovládá.

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

Hodnota rezistorů by se měla buď zvětšit alespoň na 100k, nebo rezistory úplně odstranit.

roman-dvorak, 2023-11-19:
Označme je jako DNF, neodstranoval bych je.

roman-dvorak, 2023-11-26:
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

Closed 2023-11-28.

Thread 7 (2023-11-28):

Insecure clearance between GND and active signal in buttons footprint

kaklik, 2023-11-28:
Zvolené tlačítko má hybridní způsob montáže, kdy je vnější pouzdro zaletováno do díry v PCB, ale samotné kontakty tlačítka jsou SMD.
To vede na footprint v tomhle provedení.

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

Nepříjemnost, která z toho vyplývá je ani ne 0.1mm velká izolační mezera mezi výstupní nožičkou tlačítka a GND. Za takových podmínek by mohlo velmi snadno dojít k nechtěnému sepnutí tlačítka, buď mechanickým stresem, nebo i jen kondenzací vlhkosti.

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

kaklik, 2023-11-28:
Elegantně vyřešeno prohozením polarity nožiček tlačítka.

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

Closed 2023-11-28.

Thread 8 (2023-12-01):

Incorrect orientation of gauge signalling FET

kaklik, 2023-12-01:
Ve schéma je opačně zapojený Drain a Source tranzistoru, který aktivuje rozvícení indikačních LED.

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

Bohužel se mi ne podařilo najít jiný tranzistor, který by měl na pinu 3 pouzdra SOT-23 source místo drain.

kaklik, 2023-12-05:
Řešením je tranzistoru ohnout nožičky opačně a neletovat ho na záda takhle šikmo.

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

Closed 2025-05-14.

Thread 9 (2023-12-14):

Possibly incorrect footprint of LEDs

kaklik, 2023-12-14:
Letování LED v reflow, nebo i horkým vzduchem má nyní mizernou chybovost. Je potřeba ověřit zda není možné současný footprint nějak vylepšit, aby se předešlo vysoké míře oprav.

kaklik, 2025-05-14:
Tak jsem při změně footprintu:

- Zarovnal LED podle vzdálenější od okraje desky
- Prokovy ploškách jsem posunul doprostřed, aby nevytvářely asymetrii plošek
- Připojovací cesty jsem upravil tak, aby prohřátí plošek bylo více homogenní.

Closed 2025-05-14.

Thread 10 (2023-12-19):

Cell socket polarity missing in the silkscreen

kaklik, 2023-12-19:
Ze silkscreenu není vidět polarita osazení bateriového pouzdra.

Closed 2025-05-14.

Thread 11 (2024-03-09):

Improve clearance around cell fuses

kaklik, 2024-03-09:
Hodilo by se zvětšit bezpečný prostor v okolí pojistek jednotlivých článků.  Aby se například nemohla opakovat situace, kdy nepozorností při skládání dojde k ohnutí držáku pojistky tak, že ohnutý kontakt zkratuje bateriový článek.

Closed 2025-05-14.

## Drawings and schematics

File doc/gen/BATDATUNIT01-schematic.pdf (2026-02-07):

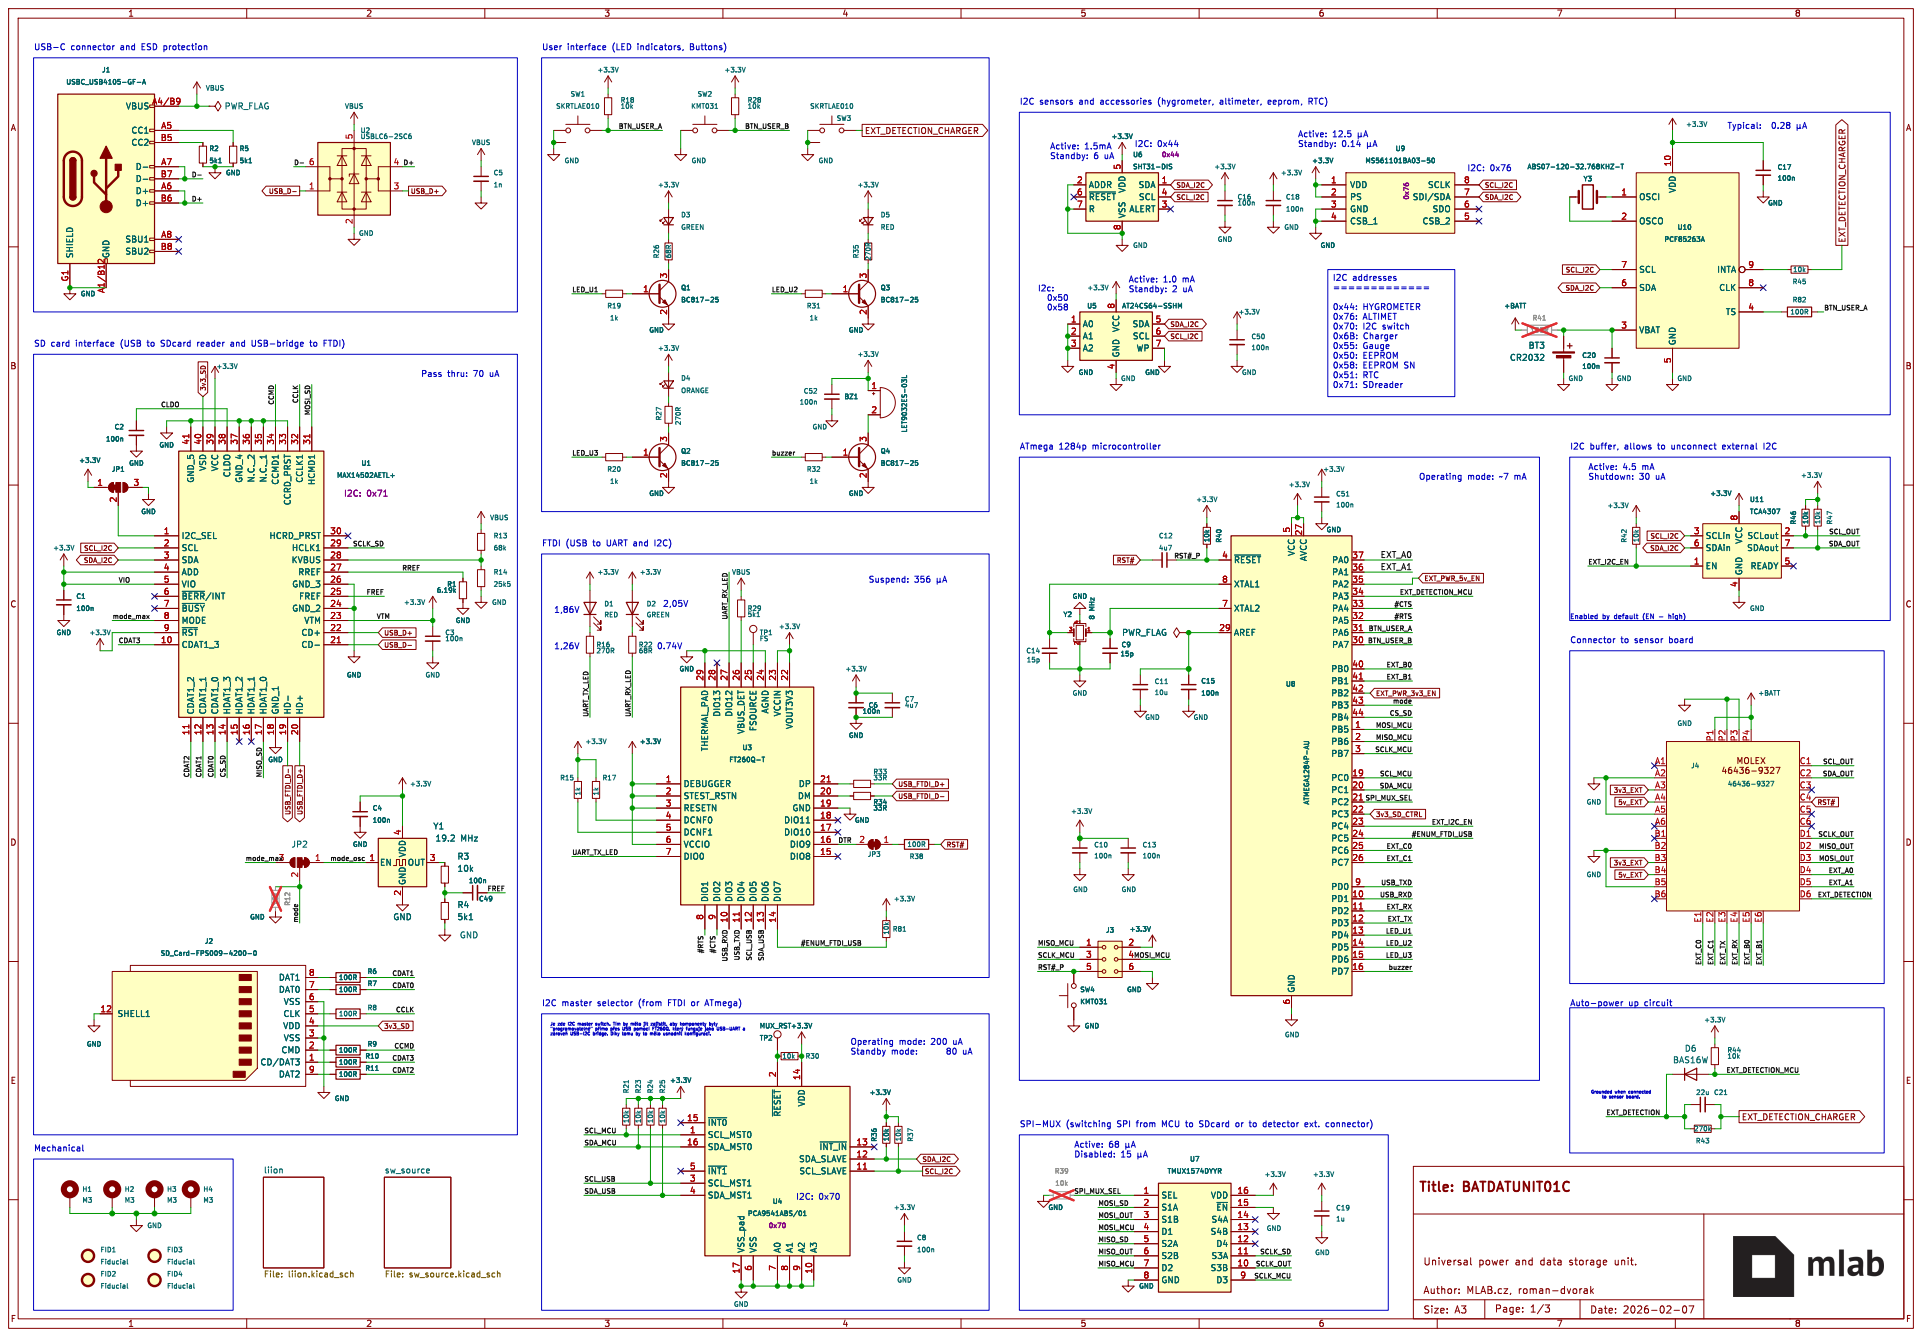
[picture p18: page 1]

8 SDA 1 SCL 4 ALERT 3 U6SHT31-DIS

3 2 Q2 BC817-25 OSCI 1 OSCO 2 SCL 7 SDA 6 VBAT 3 VDD 10 GND

8 SDA 1 SCL 4 ALERT 3 GND

4 SDA 5 SCL 6 WP 7 U5 AT24CS64-SSHM

4 SDA 5 SCL 6 WP 7 GND

9 DIO12 27 DIO3 10 VBUS_DET 26 DIO4 11 FSOURCE 25 DIO5 12 AGND 24 DIO6 13 VCCIN 23 DIO7 14 VOUT3V3 22 DP 21 DM 20 GND 19 DIO11 18 DIO10 17 DIO9 16 DIO8 15 U3 FT260Q-T

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

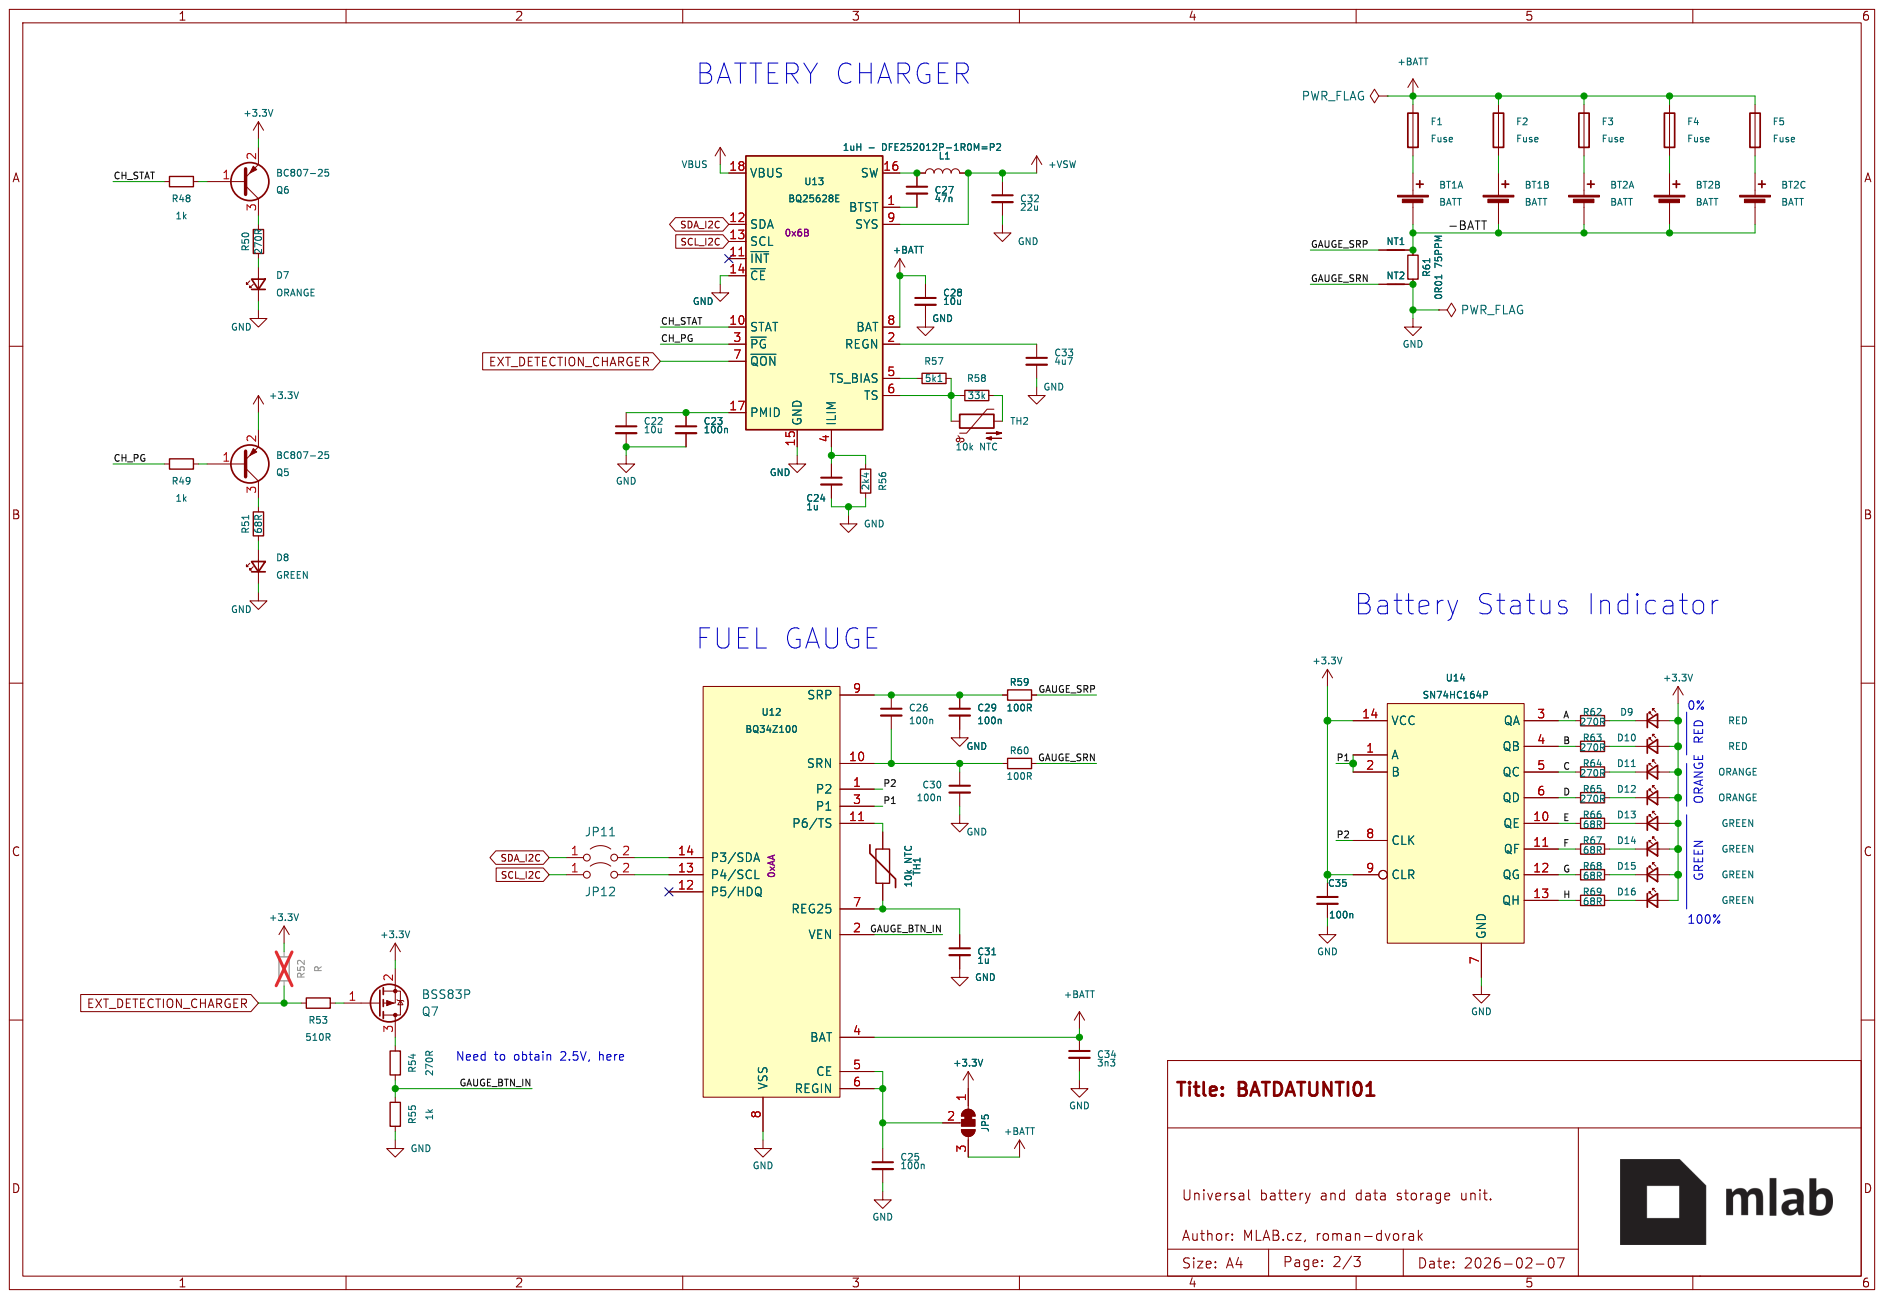
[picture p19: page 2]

4 SW 16 BTST 1 SYS 9 BAT 8 REGN 2 TS_BIAS 5 TS 6 GND

4 SW 16 BTST 1 SYS 9 BAT 8 REGN 2 TS_BIAS 5 TS 6 U13 BQ25628E

G Battery Status Indicator RED

8 SRP 9 SRN 10 P2 1 P1 3 P6/TS 11 REG25 7 VEN 2 BAT 4 CE 5 REGIN 6 U12 BQ34Z100 0xAA

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

Need to obtain 2.5V, here

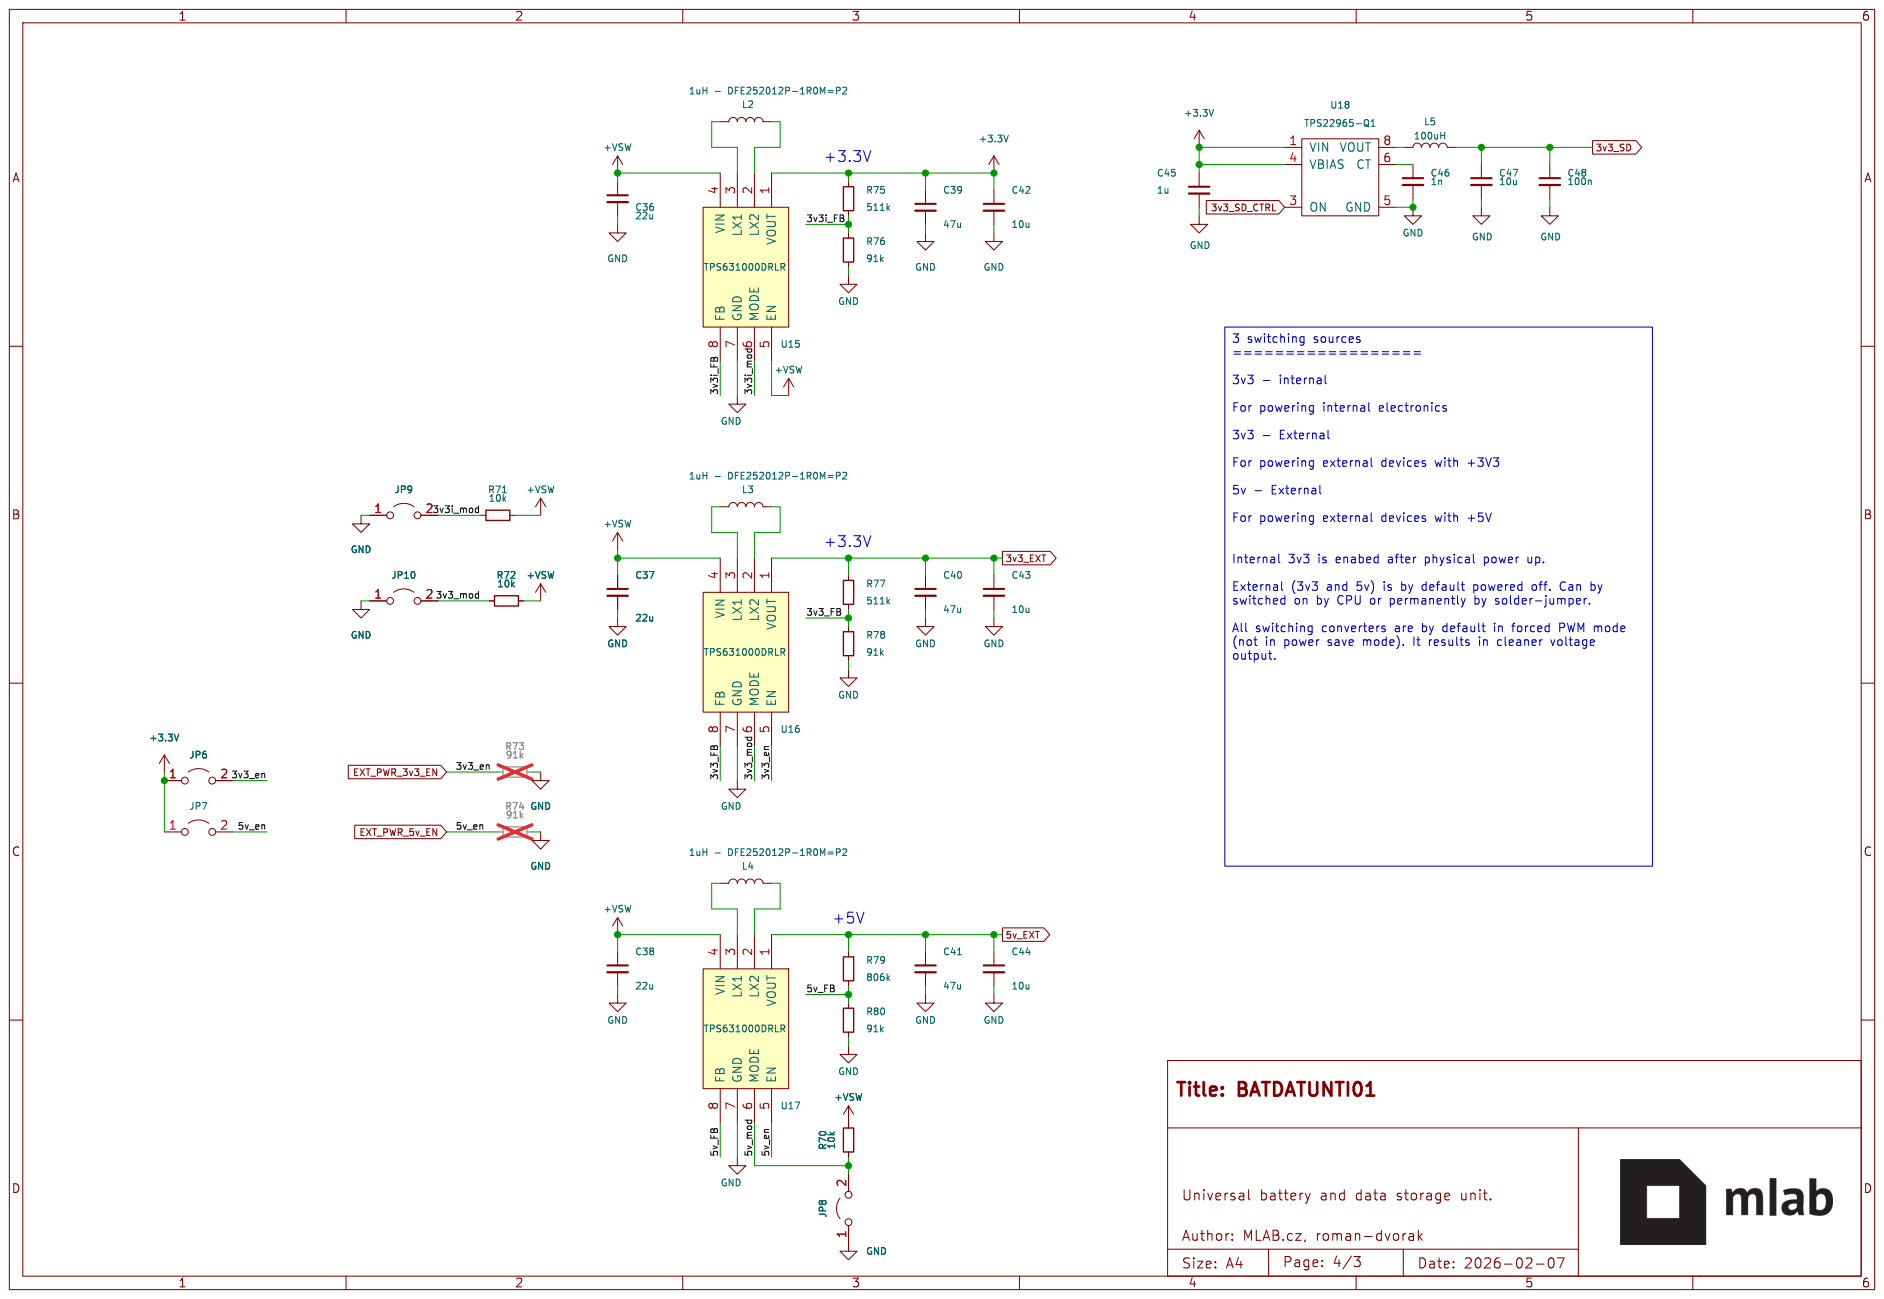
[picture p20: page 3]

(not in power save mode). It results in cleaner voltage

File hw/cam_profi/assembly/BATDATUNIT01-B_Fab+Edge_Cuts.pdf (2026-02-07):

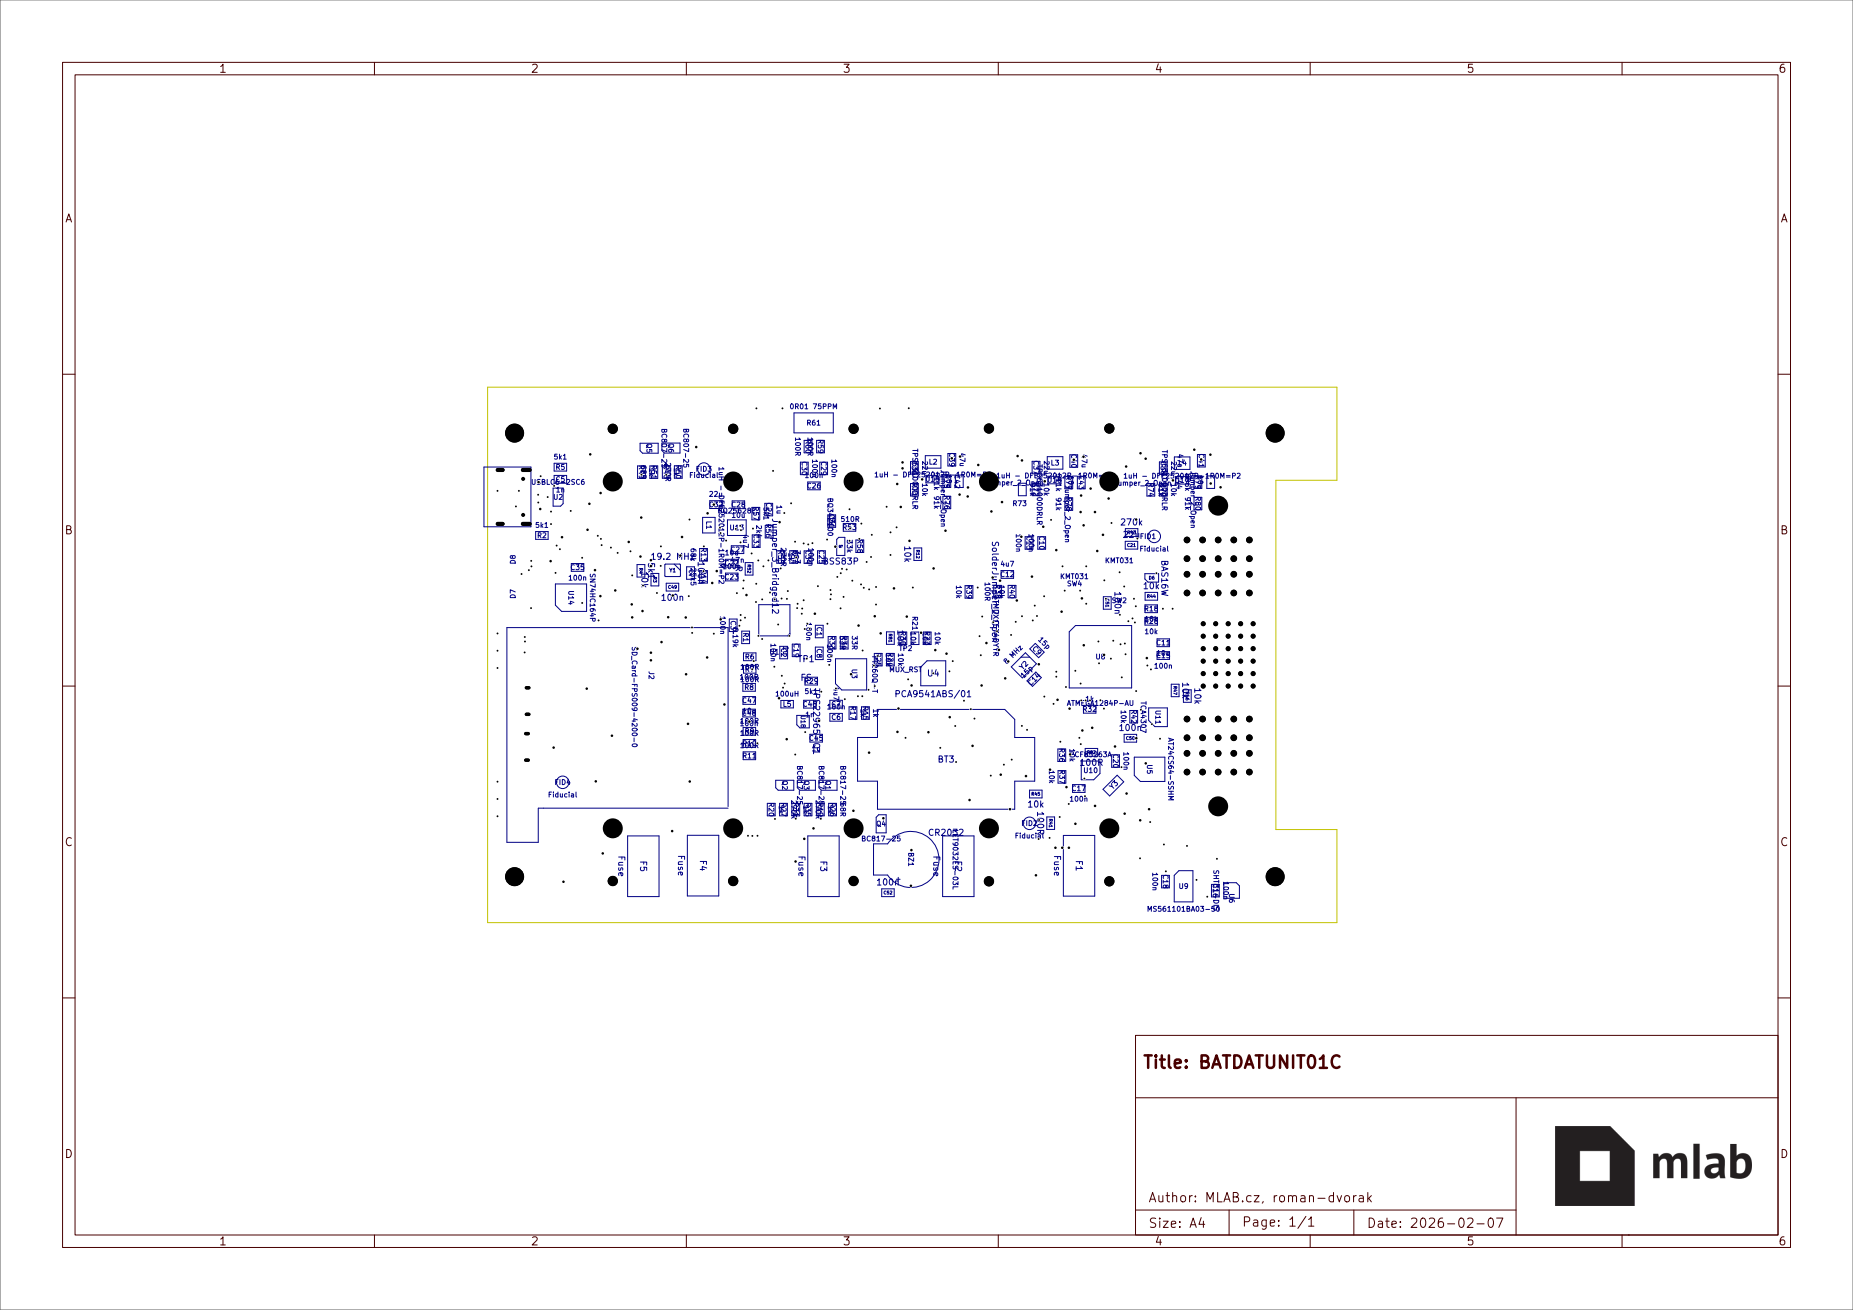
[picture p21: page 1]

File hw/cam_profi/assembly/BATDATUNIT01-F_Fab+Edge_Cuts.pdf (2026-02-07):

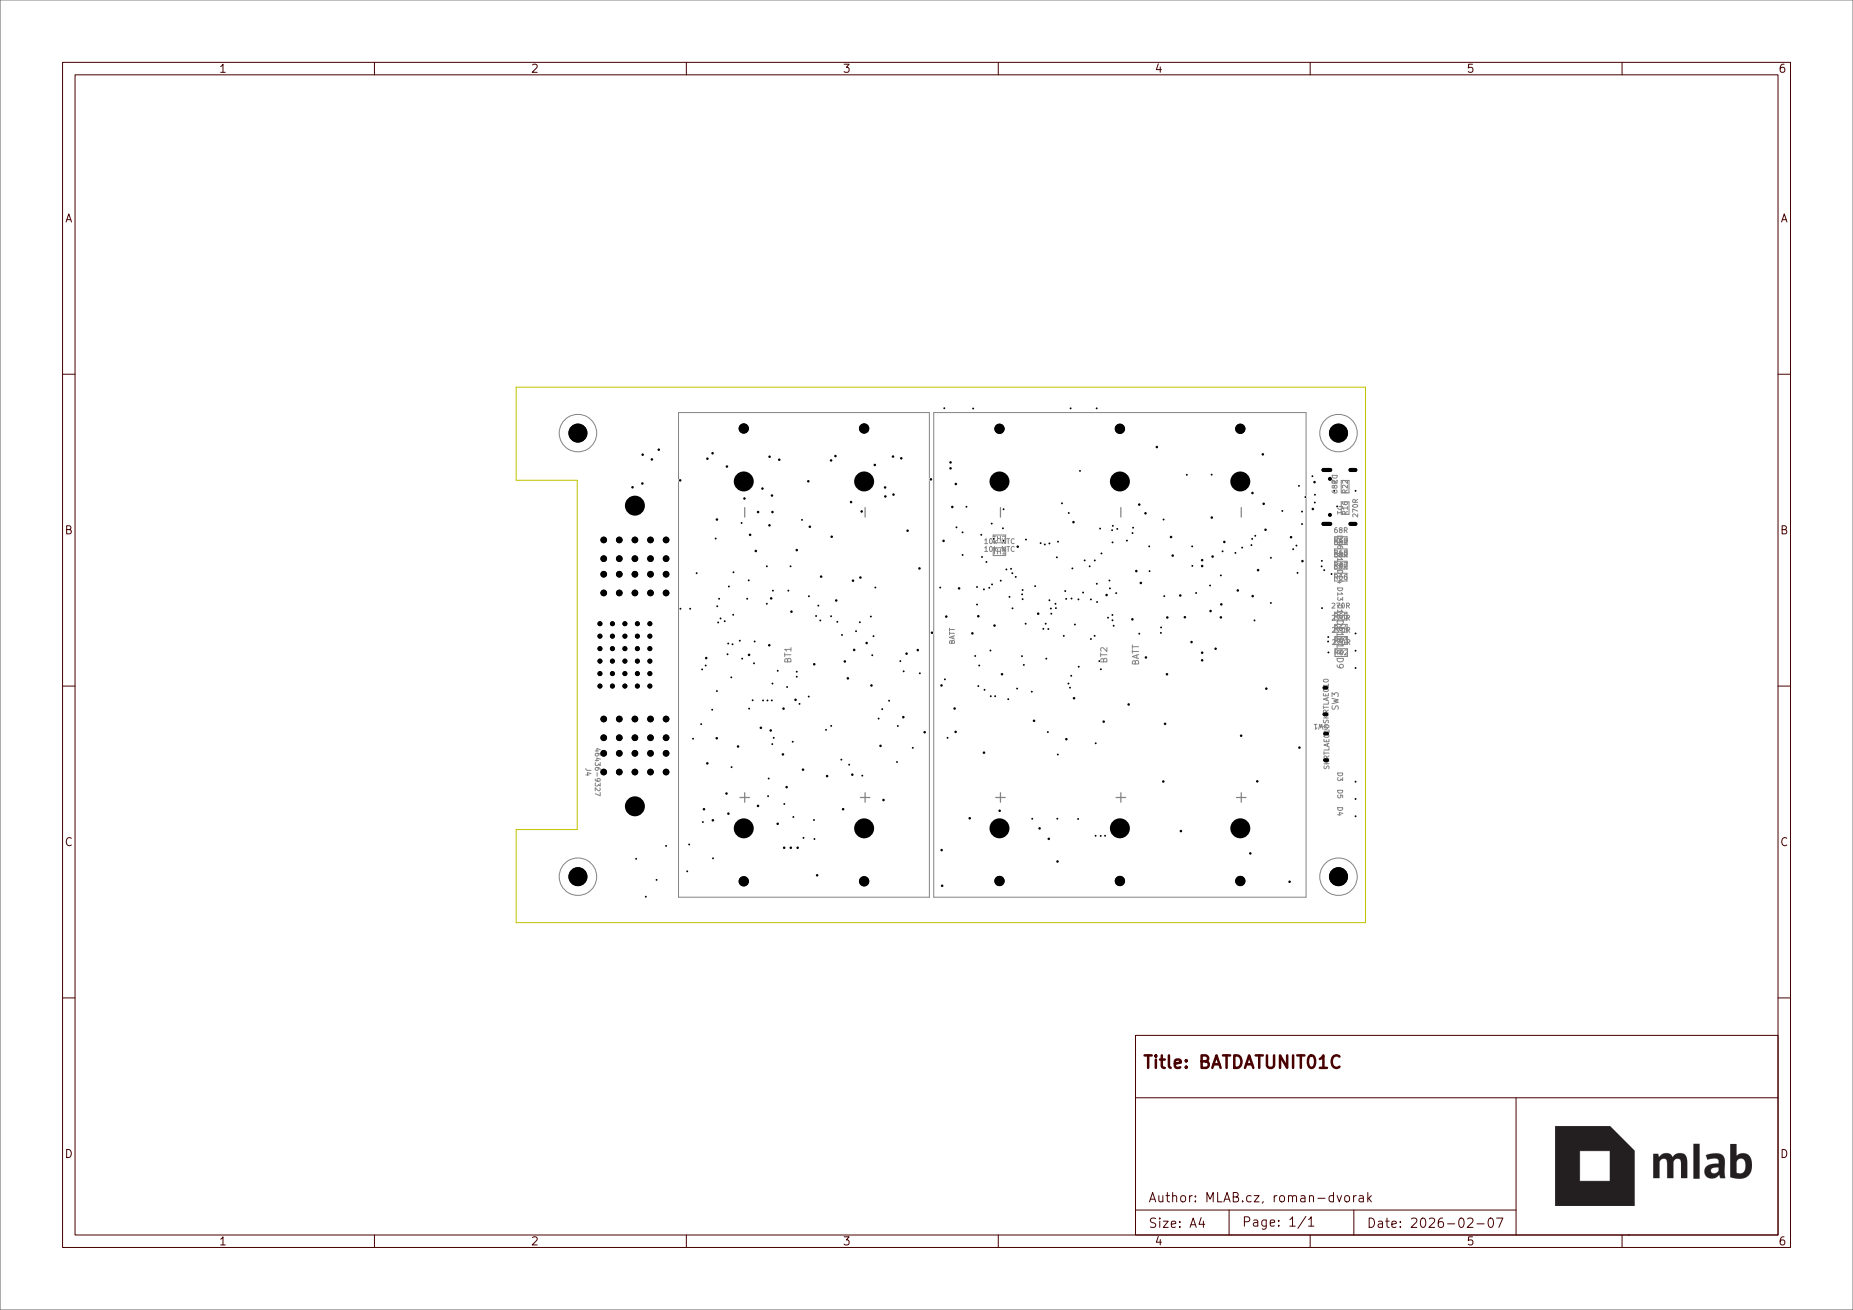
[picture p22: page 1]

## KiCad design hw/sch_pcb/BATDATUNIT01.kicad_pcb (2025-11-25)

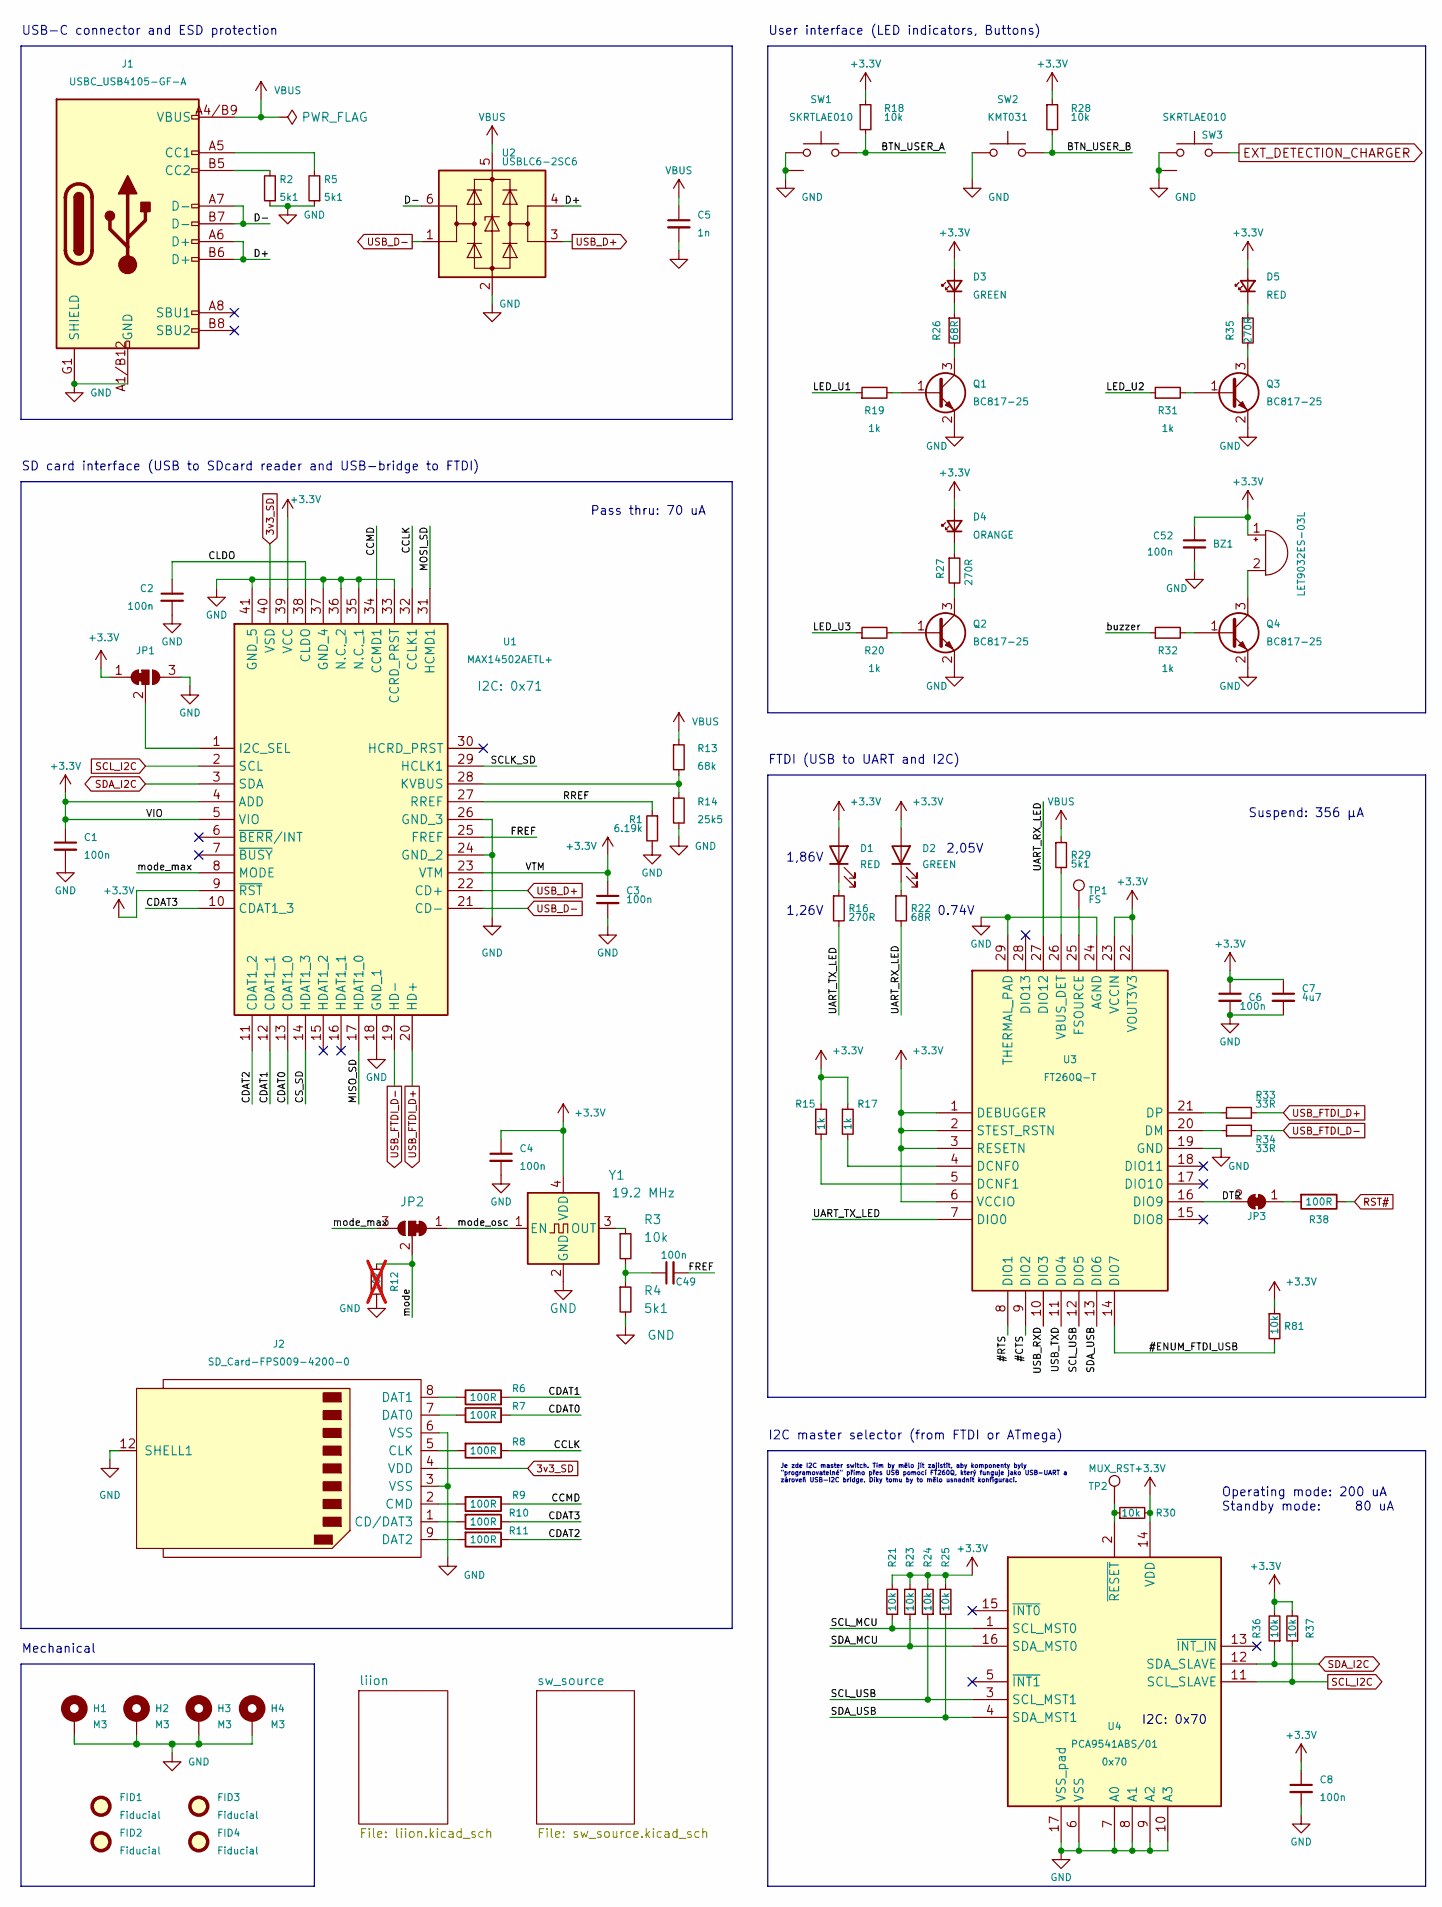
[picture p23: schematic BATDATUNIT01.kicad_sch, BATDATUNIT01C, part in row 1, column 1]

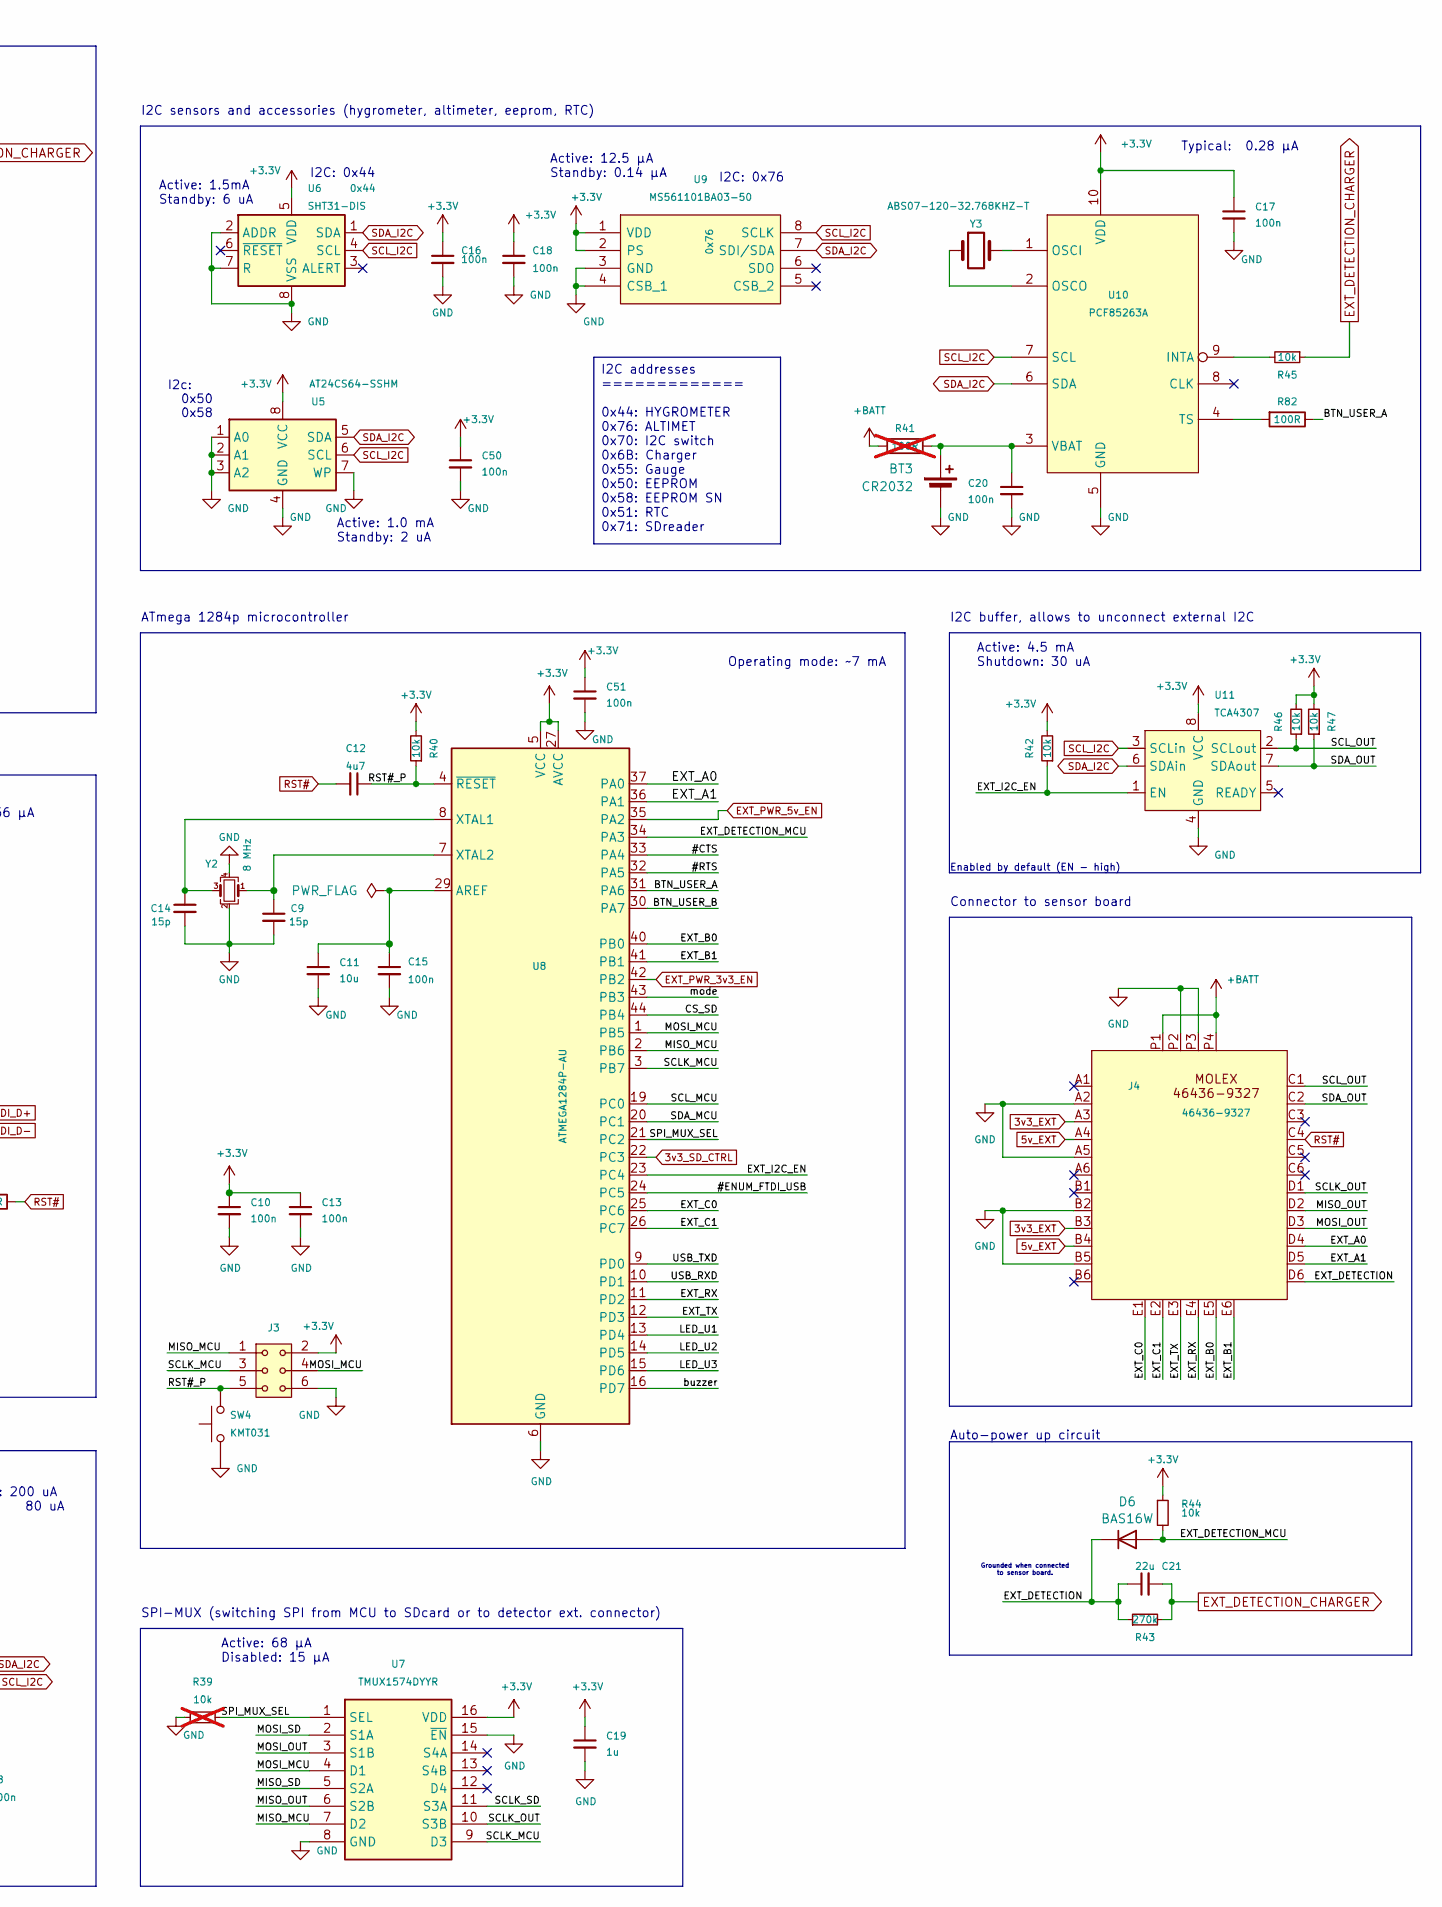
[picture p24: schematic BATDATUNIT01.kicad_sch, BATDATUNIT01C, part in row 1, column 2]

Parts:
BT3: CR2032; BatteryHolder_Keystone_1060_1x2032
BZ1: LET9032ES-03L; MagneticBuzzer_LET9032ES-03L-2.7-16-R
C1, C2, C3, C4, C6, C8, C10, C13, C15, C16, C17, C18, C20, C49, C50, C51, C52: 100n; C_0805_2012Metric
C5: 1n; C_0805_2012Metric; MPN C0805 1u
C7, C12: 4u7; C_0805_2012Metric
C9, C14: 15p; C_0805_2012Metric
C11: 10u; C_0805_2012Metric
C19: 1u; C_0805_2012Metric
C21: 22u; C_0805_2012Metric
D1, D5: RED; SMD_LED_RIGHT_KINGBRIGHT_1605
D2, D3: GREEN; SMD_LED_RIGHT_KINGBRIGHT_1605
D4: ORANGE; SMD_LED_RIGHT_KINGBRIGHT_1605
D6: BAS16W; SOT-323_SC-70
FID1, FID2, FID3, FID4: Fiducial; Fiducial_1mm_Mask2mm
H1, H2, H3, H4: M3; MountingHole_3mm
J1: USBC_USB4105-GF-A; USBC GCT_USB4105-GF-A; MPN USB4105-GF-A
J2: SD_Card-FPS009-4200-0; FPS009-4200-0
J3: HEADER_2x03; SMD_2x03
J4: 46436-9327; MOLEX_46436-9327
JP1: Jumper_3_Bridged12; SolderJumper-3_P1.3mm_Bridged2Bar12_RoundedPad1.0x1.5mm
JP2: SolderJumper_3_Bridged123; SolderJumper-3_P1.3mm_Bridged12_RoundedPad1.0x1.5mm
JP3: SolderJumper_2_Open; SolderJumper-2_P1.3mm_Bridged_RoundedPad1.0x1.5mm
Q1, Q2, Q3, Q4: BC817-25; SOT-23-3
R1: 6.19k; R_0805_2012Metric
R2, R4, R5, R29: 5k1; R_0805_2012Metric
R3, R18, R21, R23, R24, R25, R28, R30, R36, R37, R40, R42, R44, R45, R46, R47, R81: 10k; R_0805_2012Metric
R6, R7, R8, R9, R10, R11, R38, R82: 100R; R_0805_2012Metric
R12, R39: 10k; R_0805_2012Metric; not fitted
R13: 68k; R_0805_2012Metric
R14: 25k5; R_0805_2012Metric
R15, R17, R19, R20, R31, R32: 1k; R_0805_2012Metric
R16, R27, R35: 270R; R_0805_2012Metric
R22, R26: 68R; R_0805_2012Metric
R33, R34: 33R; R_0805_2012Metric
R41: 100R; R_0805_2012Metric; not fitted
R43: 270k; R_0805_2012Metric
SW1, SW3: SKRTLAE010; SKRT
SW2, SW4: KMT031; KMT031 NGJ LHS C&K
TP1: FS; TestPoint_Pad_D1.0mm
TP2: MUX_RST; TestPoint_Pad_D1.5mm
U1: MAX14502AETL+; QFN40P500X500X80-41N; Manufacturer_Part_Number MAX14502AETL+
U2: USBLC6-2SC6; SOT-23-6; LCSC C7519
U3: FT260Q-T; QFN-28-1EP_5x5mm_P0.5mm_EP3.35x3.35mm; Manufacturer_Part_Number FT260Q-T; Mouser Part Number 895-FT260Q-T
U4: PCA9541ABS/01; QFN-16-1EP_4x4mm_P0.65mm_EP2.15x2.15mm; Manufacturer_Part_Number PCA9541ABS/03,118; Mouser Part Number 771-PCA9541ABS03,118
U5: AT24CS64-SSHM; SOIC-8_3.9x4.9mm_P1.27mm
U6: SHT31-DIS; Sensirion_DFN-8-1EP_2.5x2.5mm_P0.5mm_EP1.1x1.7mm
U7: TMUX1574DYYR; SOT-23-16 THIN; Manufacturer_Part_Number TMUX1574DYYR; Mouser Part Number 595-TMUX1574DYYR
U8: ATMEGA1284P-AU; TQFP-44_10x10mm_P0.8mm
U9: MS561101BA03-50; LGA-8_3x5mm_P1.25mm; Mouser Part Number 824-MS561101BA03-50
U10: PCF85263A; TSSOP-10_3x3mm_P0.5mm
U11: TCA4307; VSSOP-8_3.0x3.0mm_P0.65mm
Y1: 19.2 MHz; Crystal_SMD_2520-4Pin_2.5x2.0mm
Y2: 8 MHz; Crystal_SMD_3225-4Pin_3.2x2.5mm
Y3: ABS07-120-32.768KHZ-T; ABS07

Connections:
3v3_EXT: J4.A3, J4.B3; also elsewhere on the board
3v3_SD: J2.4 (VDD), U1.40 (VSD); also elsewhere on the board
3v3_SD_CTRL: U8.22 (PC3); also elsewhere on the board
5v_EXT: J4.A4, J4.B4; also elsewhere on the board
+3.3V: BZ1.1 (-), C1.1, C3.1, C4.1, C6.1, C7.1, C8.1, C10.1, C13.1, C16.1, C17.1, C18.1, C19.1, C50.1, C51.1, C52.1, D1.2 (A), D2.2 (A), D3.2 (A), D4.2 (A), D5.2 (A), J3.2, JP1.1 (A), R15.1, R17.1, R18.1, R21.2, R23.2, R24.2, R25.2, R28.1, R30.2, R36.2, R37.2, R40.2, R42.2, R44.1, R46.2, R47.2, R81.1, U1.4 (ADD), U1.5 (VIO), U1.9 (~RST), U1.23 (VTM), U1.39 (VCC), U3.1 (DEBUGGER), U3.2 (STEST_RSTN), U3.3 (RESETN), U3.6 (VCCIO), U3.22 (VOUT3V3), U3.23 (VCCIN), U4.14 (VDD), U5.8 (VCC), U6.5 (VDD), U7.16 (VDD), U8.5 (VCC), U8.17 (VCC), U8.27 (AVCC), U8.38 (VCC), U9.1 (VDD), U9.2 (PS), U10.10 (VDD), U11.8 (VCC), Y1.4 (VDD); also elsewhere on the board
+BATT: J4.P1, J4.P4, R41.2; also elsewhere on the board
/#CTS: U3.9 (DIO2), U8.33 (PA4)
/#ENUM_FTDI_USB: R81.2, U3.14 (DIO7), U8.24 (PC5)
/#RTS: U3.8 (DIO1), U8.32 (PA5)
/BTN_USER_A: R18.2, R82.1, SW1.1, U8.31 (PA6)
/BTN_USER_B: R28.2, SW2.1, U8.30 (PA7)
/CCLK: R8.1, U1.32 (CCLK1)
/CCMD: R9.1, U1.34 (CCMD1)
/CDAT0: R7.2, U1.13 (CDAT1_0)
/CDAT1: R6.2, U1.12 (CDAT1_1)
/CDAT2: R11.1, U1.11 (CDAT1_2)
/CDAT3: R10.1, U1.10 (CDAT1_3)
/CLDO: C2.1, U1.38 (CLDO)
/CS_SD: U1.14 (HDAT1_3), U8.44 (PB4)
/D+: J1.A6 (D+), J1.B6 (D+), U2.4 (I/O2)
/D-: J1.A7 (D-), J1.B7 (D-), U2.6 (I/O1)
/DTR: JP3.2 (B), U3.16 (DIO9)
/EXT_A0: J4.D4, U8.37 (PA0)
/EXT_A1: J4.D5, U8.36 (PA1)
/EXT_B0: J4.E5, U8.40 (PB0)
/EXT_B1: J4.E6, U8.41 (PB1)
/EXT_C0: J4.E1, U8.25 (PC6)
/EXT_C1: J4.E2, U8.26 (PC7)
/EXT_DETECTION: C21.1, D6.3 (K), J4.D6, R43.1
/EXT_DETECTION_MCU: D6.1 (A), R44.2, U8.34 (PA3)
/EXT_I2C_EN: R42.1, U8.23 (PC4), U11.1 (EN)
/EXT_RX: J4.E4, U8.11 (PD2)
/EXT_TX: J4.E3, U8.12 (PD3)
/FREF: C49.2, U1.25 (FREF)
/LED_U1: R19.1, U8.13 (PD4)
/LED_U2: R31.1, U8.14 (PD5)
/LED_U3: R20.1, U8.15 (PD6)
/MISO_MCU: J3.1, U7.7 (D2), U8.2 (PB6)
/MISO_OUT: J4.D2, U7.6 (S2B)
/MISO_SD: U1.17 (HDAT1_0), U7.5 (S2A)
/MOSI_MCU: J3.4, U7.4 (D1), U8.1 (PB5)
/MOSI_OUT: J4.D3, U7.3 (S1B)
/MOSI_SD: U1.31 (HCMD1), U7.2 (S1A)
/RREF: R1.1, U1.27 (RREF)
/RST#_P: C12.1, J3.5, R40.1, SW4.2, U8.4 (~RESET)
/SCLK_MCU: J3.3, U7.9 (D3), U8.3 (PB7)
/SCLK_OUT: J4.D1, U7.10 (S3B)
/SCLK_SD: U1.29 (HCLK1), U7.11 (S3A)
/SCL_MCU: R21.1, U4.1 (SCL_MST0), U8.19 (PC0)
/SCL_OUT: J4.C1, R46.1, U11.2 (SCLout)
/SCL_USB: R24.1, U3.12 (DIO5), U4.3 (SCL_MST1)
/SDA_MCU: R23.1, U4.16 (SDA_MST0), U8.20 (PC1)
/SDA_OUT: J4.C2, R47.1, U11.7 (SDAout)
/SDA_USB: R25.1, U3.13 (DIO6), U4.4 (SDA_MST1)
/SPI_MUX_SEL: R39.2, U7.1 (SEL), U8.21 (PC2)
/UART_RX_LED: R22.2, U3.27 (DIO12)
/UART_TX_LED: R16.2, U3.7 (DIO0)
/USB_RXD: U3.10 (DIO3), U8.10 (PD1)
/USB_TXD: U3.11 (DIO4), U8.9 (PD0)
/buzzer: R32.1, U8.16 (PD7)
/mode: JP2.2 (C), R12.2, U8.43 (PB3)
/mode_max: JP2.3 (B), U1.8 (MODE)
/mode_osc: JP2.1 (A), Y1.1 (EN)
EXT_DETECTION_CHARGER: C21.2, R43.2, R45.1, SW3.1; also elsewhere on the board
EXT_PWR_3v3_EN: U8.42 (PB2); also elsewhere on the board
EXT_PWR_5v_EN: U8.35 (PA2); also elsewhere on the board
GND: BT3.2 (-), C1.2, C2.2, C3.2, C4.2, C5.2, C6.2, C7.2, C8.2, C9.2, C10.2, C11.2, C13.2, C14.2, C15.2, C16.2, C17.2, C18.2, C19.2, C20.2, C50.2, C51.2, C52.2, H1.1, H2.1, H3.1, H4.1, J1.A1/B12 (GND), J1.B1/A12 (GND), J1.G1 (SHIELD), J1.G2 (SHIELD), J1.G3 (SHIELD), J1.G4 (SHIELD), J2.3 (VSS), J2.6 (VSS), J2.12 (SHELL1), J3.6, J4.A2, J4.A5, J4.B2, J4.B5, J4.P2, J4.P3, JP1.3 (B), Q1.2 (E), Q2.2 (E), Q3.2 (E), Q4.2 (E), R1.2, R2.1, R4.2, R5.1, R12.1, R14.2, R39.1, SW1.2, SW1.GND (SHIELD), SW2.2, SW3.2, SW3.GND (SHIELD), SW4.1, U1.18 (GND_1), U1.24 (GND_2), U1.26 (GND_3), U1.33 (CCRD_PRST), U1.35 (N.C._1), U1.36 (N.C._2), U1.37 (GND_4), U1.41 (GND_5), U2.2 (GND), U3.19 (GND), U3.24 (AGND), U3.29 (THERMAL_PAD), U4.6 (VSS), U4.7 (A0), U4.8 (A1), U4.9 (A2), U4.10 (A3), U4.17 (VSS_pad), U5.1 (A0), U5.2 (A1), U5.3 (A2), U5.4 (GND), U5.7 (WP), U6.2 (ADDR), U6.7 (R), U6.8 (VSS), U6.9 (VSS), U7.8 (GND), U7.15 (~EN), U8.6 (GND), U8.18 (GND), U8.28 (GND), U8.39 (GND), U9.3 (GND), U9.4 (CSB_1), U10.5 (GND), U11.4 (GND), Y1.2 (GND), Y2.2, Y2.4; also elsewhere on the board
unnamed: BT3.1 (+), C20.1, R41.1, U10.3 (VBAT)
unnamed: BZ1.2 (+), Q4.3 (C)
unnamed: C49.1, R3.2, R4.1
unnamed: D1.1 (K), R16.1
unnamed: D2.1 (K), R22.1
unnamed: D3.1 (K), R26.1
unnamed: D4.1 (K), R27.1
unnamed: D5.1 (K), R35.1
unnamed: J1.A5 (CC1), R5.2
unnamed: J1.B5 (CC2), R2.2
unnamed: J2.1 (CD/DAT3), R10.2
unnamed: J2.5 (CLK), R8.2
unnamed: J2.2 (CMD), R9.2
unnamed: J2.7 (DAT0), R7.1
unnamed: J2.8 (DAT1), R6.1
unnamed: J2.9 (DAT2), R11.2
unnamed: JP1.2 (C), U1.1 (I2C_SEL)
unnamed: JP3.1 (A), R38.2
unnamed: Q1.1 (B), R19.2
unnamed: Q1.3 (C), R26.2
unnamed: Q2.1 (B), R20.2
unnamed: Q2.3 (C), R27.2
unnamed: Q3.1 (B), R31.2
unnamed: Q3.3 (C), R35.2
unnamed: Q4.1 (B), R32.2
unnamed: R13.2, R14.1, U1.28 (KVBUS)
unnamed: R17.2, U3.4 (DCNF0)
unnamed: R15.2, U3.5 (DCNF1)
unnamed: R34.1, U3.20 (DM)
unnamed: R33.1, U3.21 (DP)
unnamed: TP1.1, U3.25 (FSOURCE)
unnamed: R29.2, U3.26 (VBUS_DET)
unnamed: R30.1, TP2.1, U4.2 (~RESET)
unnamed: C11.1, C15.1, U8.29 (AREF)
unnamed: C14.1, U8.8 (XTAL1), Y2.3
unnamed: C9.1, U8.7 (XTAL2), Y2.1
unnamed: R45.2, U10.9 (INTA)
unnamed: U10.1 (OSCI), Y3.2
unnamed: U10.2 (OSCO), Y3.1
unnamed: R82.2, U10.4 (TS)
unnamed: R3.1, Y1.3 (OUT)
RST#: C12.2, J4.C4, R38.1
SCL_I2C: R37.1, U1.2 (SCL), U4.11 (SCL_SLAVE), U5.6 (SCL), U6.4 (SCL), U9.8 (SCLK), U10.7 (SCL), U11.3 (SCLin); also elsewhere on the board
SDA_I2C: R36.1, U1.3 (SDA), U4.12 (SDA_SLAVE), U5.5 (SDA), U6.1 (SDA), U9.7 (SDI/SDA), U10.6 (SDA), U11.6 (SDAin); also elsewhere on the board
USB_D+: U1.22 (CD+), U2.3 (I/O2)
USB_D-: U1.21 (CD-), U2.1 (I/O1)
USB_FTDI_D+: R33.2, U1.20 (HD+)
USB_FTDI_D-: R34.2, U1.19 (HD-)
VBUS: C5.1, J1.A4/B9 (VBUS), J1.B4/A9 (VBUS), R13.1, R29.1, U2.5 (VBUS); also elsewhere on the board

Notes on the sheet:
SPI-MUX (switching SPI from MCU to SDcard or to detector ext. connector)
Active: 4.5 mA Shutdown: 30 uA
Active: 1.5mA Standby: 6 uA
0.74V
Active: 1.0 mA Standby: 2 uA
Suspend: 356 μA
FTDI (USB to UART and I2C)
I2C: 0x44
Active: 12.5 μA Standby: 0.14 μA
Mechanical
I2C buffer, allows to unconnect external I2C
ATmega 1284p microcontroller
1,86V
Pass thru: 70 uA
USB-C connector and ESD protection
Typical: 0.28 μA
I2C sensors and accessories (hygrometer, altimeter, eeprom, RTC)
I2C master selector (from FTDI or ATmega)
User interface (LED indicators, Buttons)
Operating mode: ~7 mA
Auto-power up circuit
Active: 68 μA Disabled: 15 μA
Grounded when connected to sensor board.
2,05V
Connector to sensor board
I2c: 0x50 0x58
I2C: 0x76
Enabled by default (EN - high)
I2C: 0x70
1,26V
Operating mode: 200 uA Standby mode: 80 uA
SD card interface (USB to SDcard reader and USB-bridge to FTDI)
I2C addresses ============= 0x44: HYGROMETER 0x76: ALTIMET 0x70: I2C switch 0x6B: Charger 0x55: Gauge 0x50: EEPROM 0x58: EEPROM SN 0x51: RTC 0x71: SDreader
Je zde I2C master switch. Tím by mělo jít zajistit, aby komponenty byly "programovatelné" přímo přes USB pomocí FT260Q, který funguje jako USB-UART a zároveň USB-I2C bridge. Díky tomu by to mělo usnadnit konfiguraci.

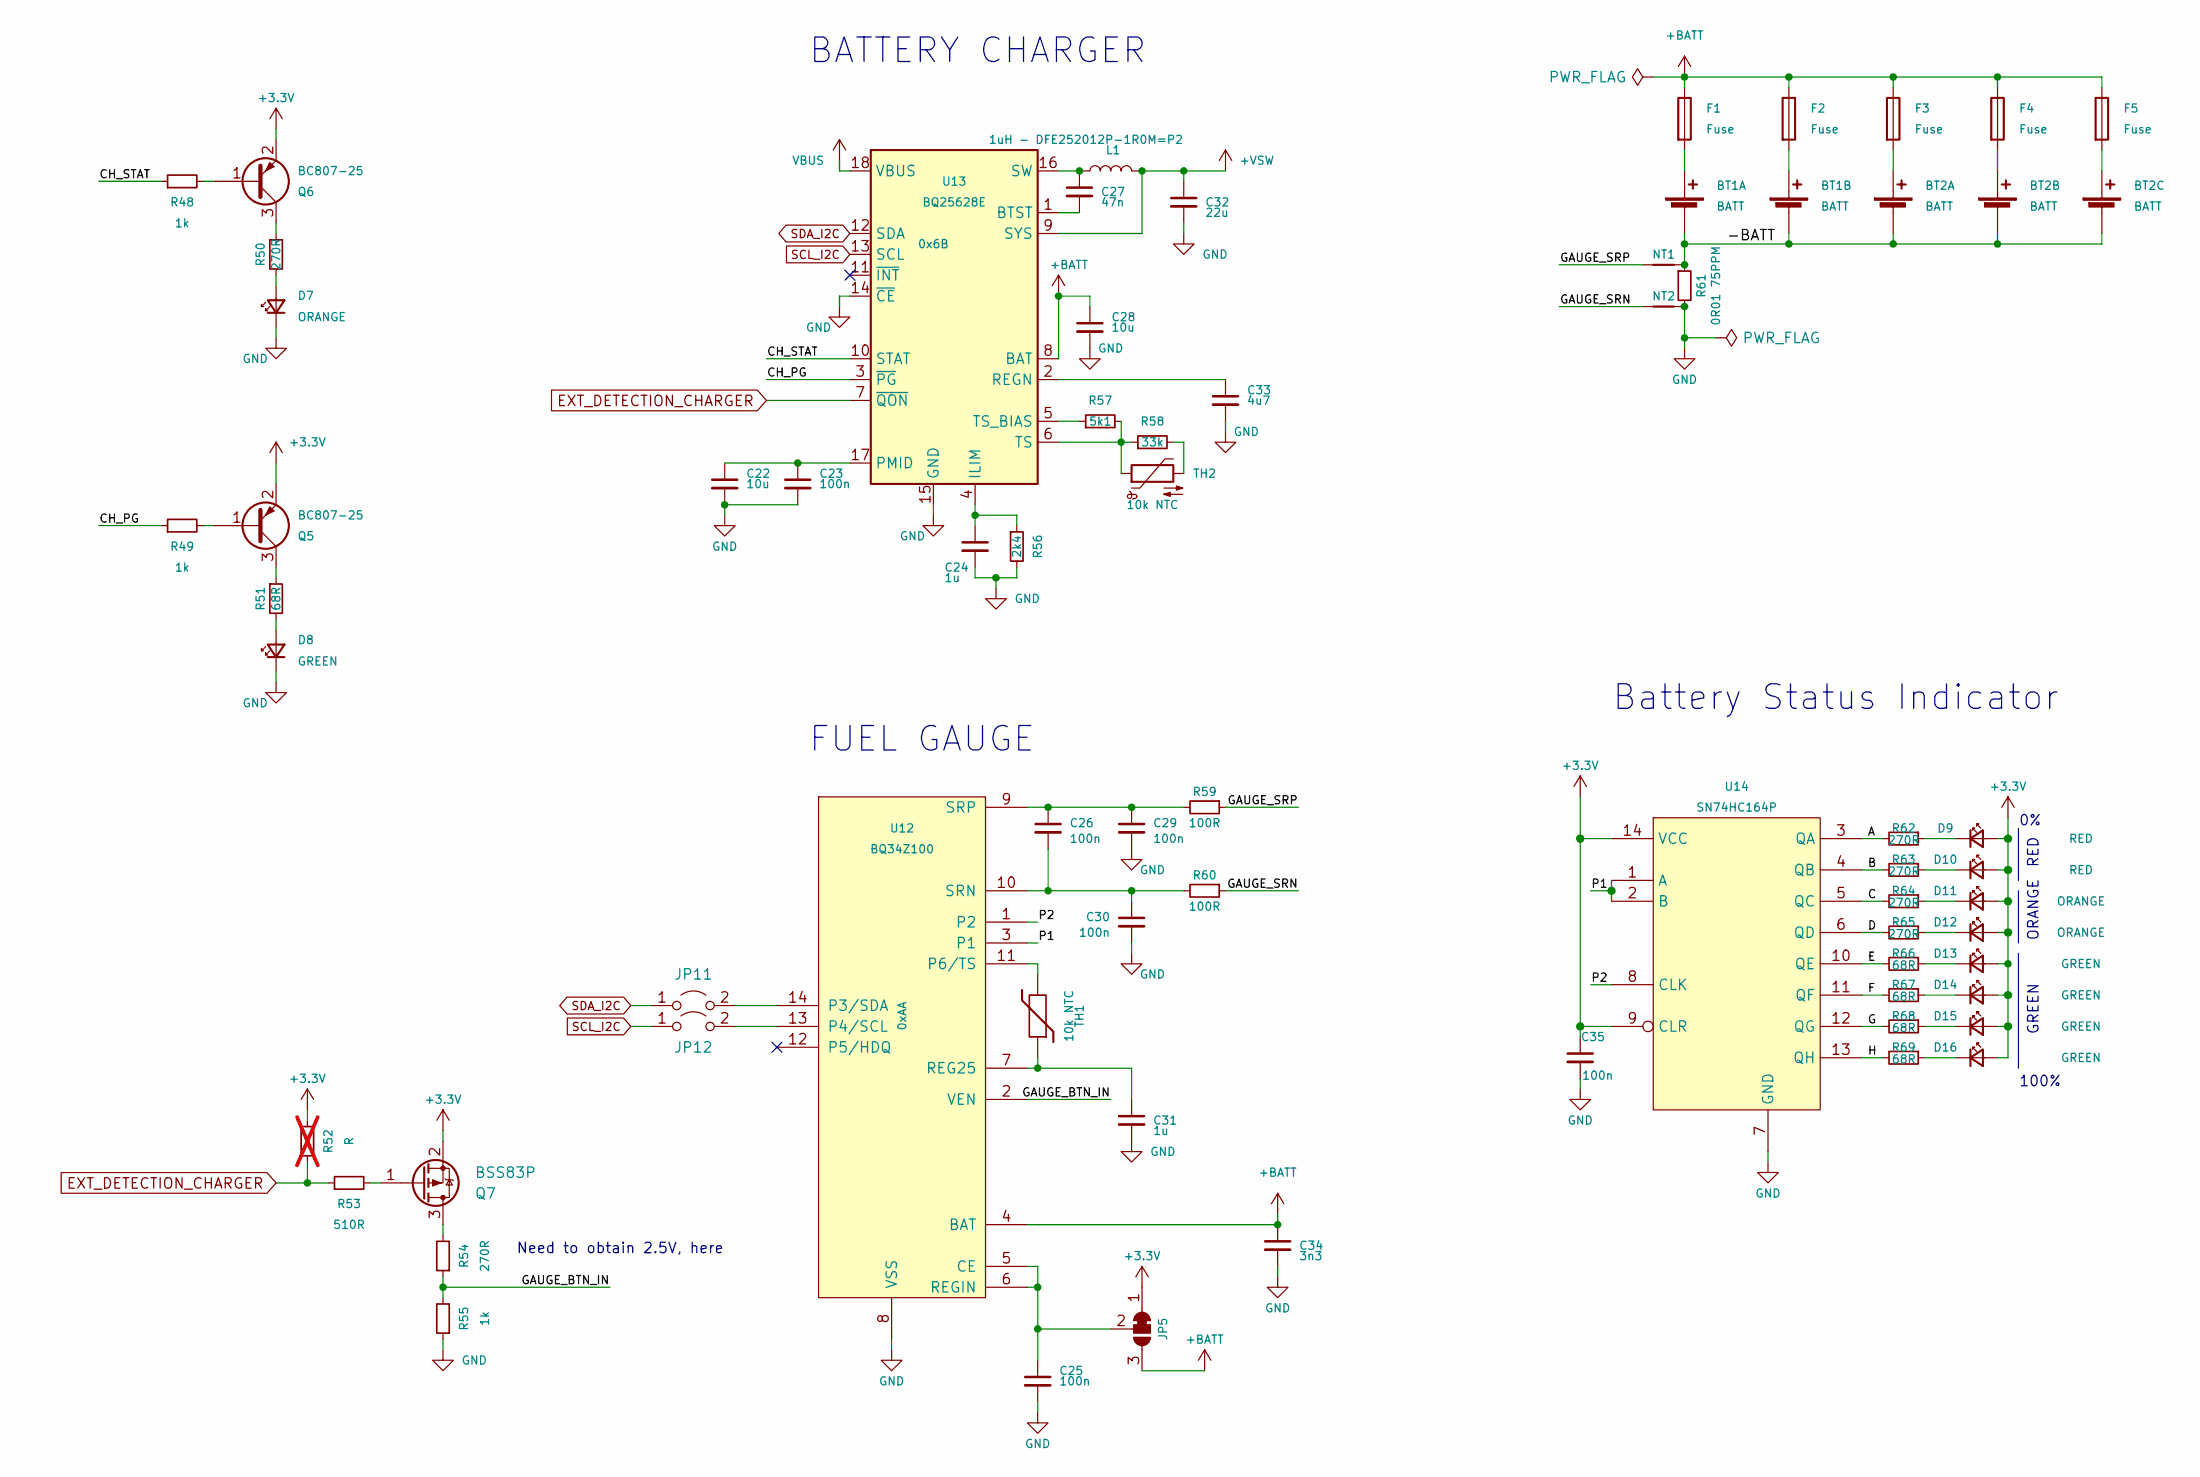
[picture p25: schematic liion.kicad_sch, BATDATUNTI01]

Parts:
BT1: BATT; BAT_BK-18650-PC4
BT2: BATT; BAT_BK-18650-PC6
C22, C28: 10u; C_0805_2012Metric
C23, C25, C26, C29, C30, C35: 100n; C_0805_2012Metric
C24, C31: 1u; C_0805_2012Metric
C27: 47n; C_0805_2012Metric
C32: 22u; C_0805_2012Metric
C33: 4u7; C_0805_2012Metric
C34: 3n3; C_0805_2012Metric
D7, D11, D12: ORANGE; SMD_LED_RIGHT_KINGBRIGHT_1605
D8, D13, D14, D15, D16: GREEN; SMD_LED_RIGHT_KINGBRIGHT_1605
D9, D10: RED; SMD_LED_RIGHT_KINGBRIGHT_1605
F1, F2, F3, F4, F5: Fuse; Fuseholder_Littelfuse_Nano2_154x
JP5: Jumper_3_Bridged12; SolderJumper-3_P1.3mm_Bridged2Bar12_RoundedPad1.0x1.5mm
JP11, JP12: Jumper_2_Open; SolderJumper-2_P1.3mm_Open_RoundedPad1.0x1.5mm
L1: 1uH - DFE252012P-1R0M=P2; L_1008_2520Metric
NT1, NT2: NetTie_2; NetTie-2_SMD_Pad0.5mm
Q5, Q6: BC807-25; SOT-23-3
Q7: BSS83P; SOT-23
R48, R49, R55: 1k; R_0805_2012Metric
R50, R54, R62, R63, R64, R65: 270R; R_0805_2012Metric
R51, R66, R67, R68, R69: 68R; R_0805_2012Metric
R52: R; R_0805_2012Metric; not fitted
R53: 510R; R_0805_2012Metric
R56: 2k4; R_0805_2012Metric
R57: 5k1; R_0805_2012Metric
R58: 33k; R_0805_2012Metric
R59, R60: 100R; R_0805_2012Metric
R61: 0R01 75PPM; R_2512_6332Metric
TH1, TH2: 10k NTC; R_0805_2012Metric
U12: BQ34Z100; TSSOP-14_4.4x5mm_Pitch0.65mm
U13: BQ25628E; Texas_S-WQFN-HR-18
U14: SN74HC164P; TSSOP-14_4.4x5mm_P0.65mm

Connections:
+3.3V: C35.1, D9.2 (A), D10.2 (A), D11.2 (A), D12.2 (A), D13.2 (A), D14.2 (A), D15.2 (A), D16.2 (A), JP5.1 (A), Q5.2 (E), Q6.2 (E), Q7.2 (S), R52.2, U14.9 (CLR), U14.14 (VCC); also elsewhere on the board
+BATT: C28.1, C34.1, F1.1, F2.1, F3.1, F4.1, F5.1, JP5.3 (B), U12.4 (BAT), U13.8 (BAT); also elsewhere on the board
+VSW: C32.1, L1.2, U13.9 (SYS); also elsewhere on the board
/liion/-BATT: BT1.1- (-), BT1.2- (-), BT2.1- (-), BT2.2- (-), BT2.3- (-), NT1.2, R61.1
/liion/A: R62.2, U14.3 (QA)
/liion/B: R63.2, U14.4 (QB)
/liion/C: R64.2, U14.5 (QC)
/liion/CH_PG: R49.1, U13.3 (~PG)
/liion/CH_STAT: R48.1, U13.10 (STAT)
/liion/D: R65.2, U14.6 (QD)
/liion/E: R66.2, U14.10 (QE)
/liion/F: R67.2, U14.11 (QF)
/liion/G: R68.2, U14.12 (QG)
/liion/GAUGE_BTN_IN: R54.1, R55.2, U12.2 (VEN)
/liion/GAUGE_SRN: NT2.1, R60.1
/liion/GAUGE_SRP: NT1.1, R59.1
/liion/H: R69.2, U14.13 (QH)
/liion/P1: U12.3 (P1), U14.1 (A), U14.2 (B)
/liion/P2: U12.1 (P2), U14.8 (CLK)
EXT_DETECTION_CHARGER: R52.1, R53.1, U13.7 (~QON); also elsewhere on the board
GND: C22.2, C23.2, C24.2, C25.2, C28.2, C29.2, C30.2, C31.2, C32.2, C33.2, C34.2, C35.2, D7.1 (K), D8.1 (K), NT2.2, R55.1, R56.2, R61.2, U12.8 (VSS), U13.14 (~CE), U13.15 (GND), U14.7 (GND); also elsewhere on the board
unnamed: BT1.1+ (+), F1.2
unnamed: BT1.2+ (+), F2.2
unnamed: BT2.1+ (+), F3.2
unnamed: BT2.2+ (+), F4.2
unnamed: BT2.3+ (+), F5.2
unnamed: D7.2 (A), R50.2
unnamed: D8.2 (A), R51.2
unnamed: D9.1 (K), R62.1
unnamed: D10.1 (K), R63.1
unnamed: D11.1 (K), R64.1
unnamed: D12.1 (K), R65.1
unnamed: D13.1 (K), R66.1
unnamed: D14.1 (K), R67.1
unnamed: D15.1 (K), R68.1
unnamed: D16.1 (K), R69.1
unnamed: C25.1, JP5.2 (C), U12.5 (CE), U12.6 (REGIN)
unnamed: JP11.2 (B), U12.14 (P3/SDA)
unnamed: JP12.2 (B), U12.13 (P4/SCL)
unnamed: Q5.1 (B), R49.2
unnamed: Q5.3 (C), R51.1
unnamed: Q6.1 (B), R48.2
unnamed: Q6.3 (C), R50.1
unnamed: Q7.3 (D), R54.2
unnamed: Q7.1 (G), R53.2
unnamed: R58.2, TH2.2
unnamed: TH1.2, U12.11 (P6/TS)
unnamed: C31.1, TH1.1, U12.7 (REG25)
unnamed: C26.2, C30.1, R60.2, U12.10 (SRN)
unnamed: C26.1, C29.1, R59.2, U12.9 (SRP)
unnamed: C27.2, U13.1 (BTST)
unnamed: C24.1, R56.1, U13.4 (ILIM)
unnamed: C22.1, C23.1, U13.17 (PMID)
unnamed: C33.1, U13.2 (REGN)
unnamed: C27.1, L1.1, U13.16 (SW)
unnamed: R57.2, R58.1, TH2.1, U13.6 (TS)
unnamed: R57.1, U13.5 (TS_BIAS)
SCL_I2C: JP12.1 (A), U13.13 (SCL); also elsewhere on the board
SDA_I2C: JP11.1 (A), U13.12 (SDA); also elsewhere on the board
VBUS: U13.18 (VBUS); also elsewhere on the board

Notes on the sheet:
Need to obtain 2.5V, here
GREEN
FUEL GAUGE
100%
RED
Battery Status Indicator
ORANGE
BATTERY CHARGER

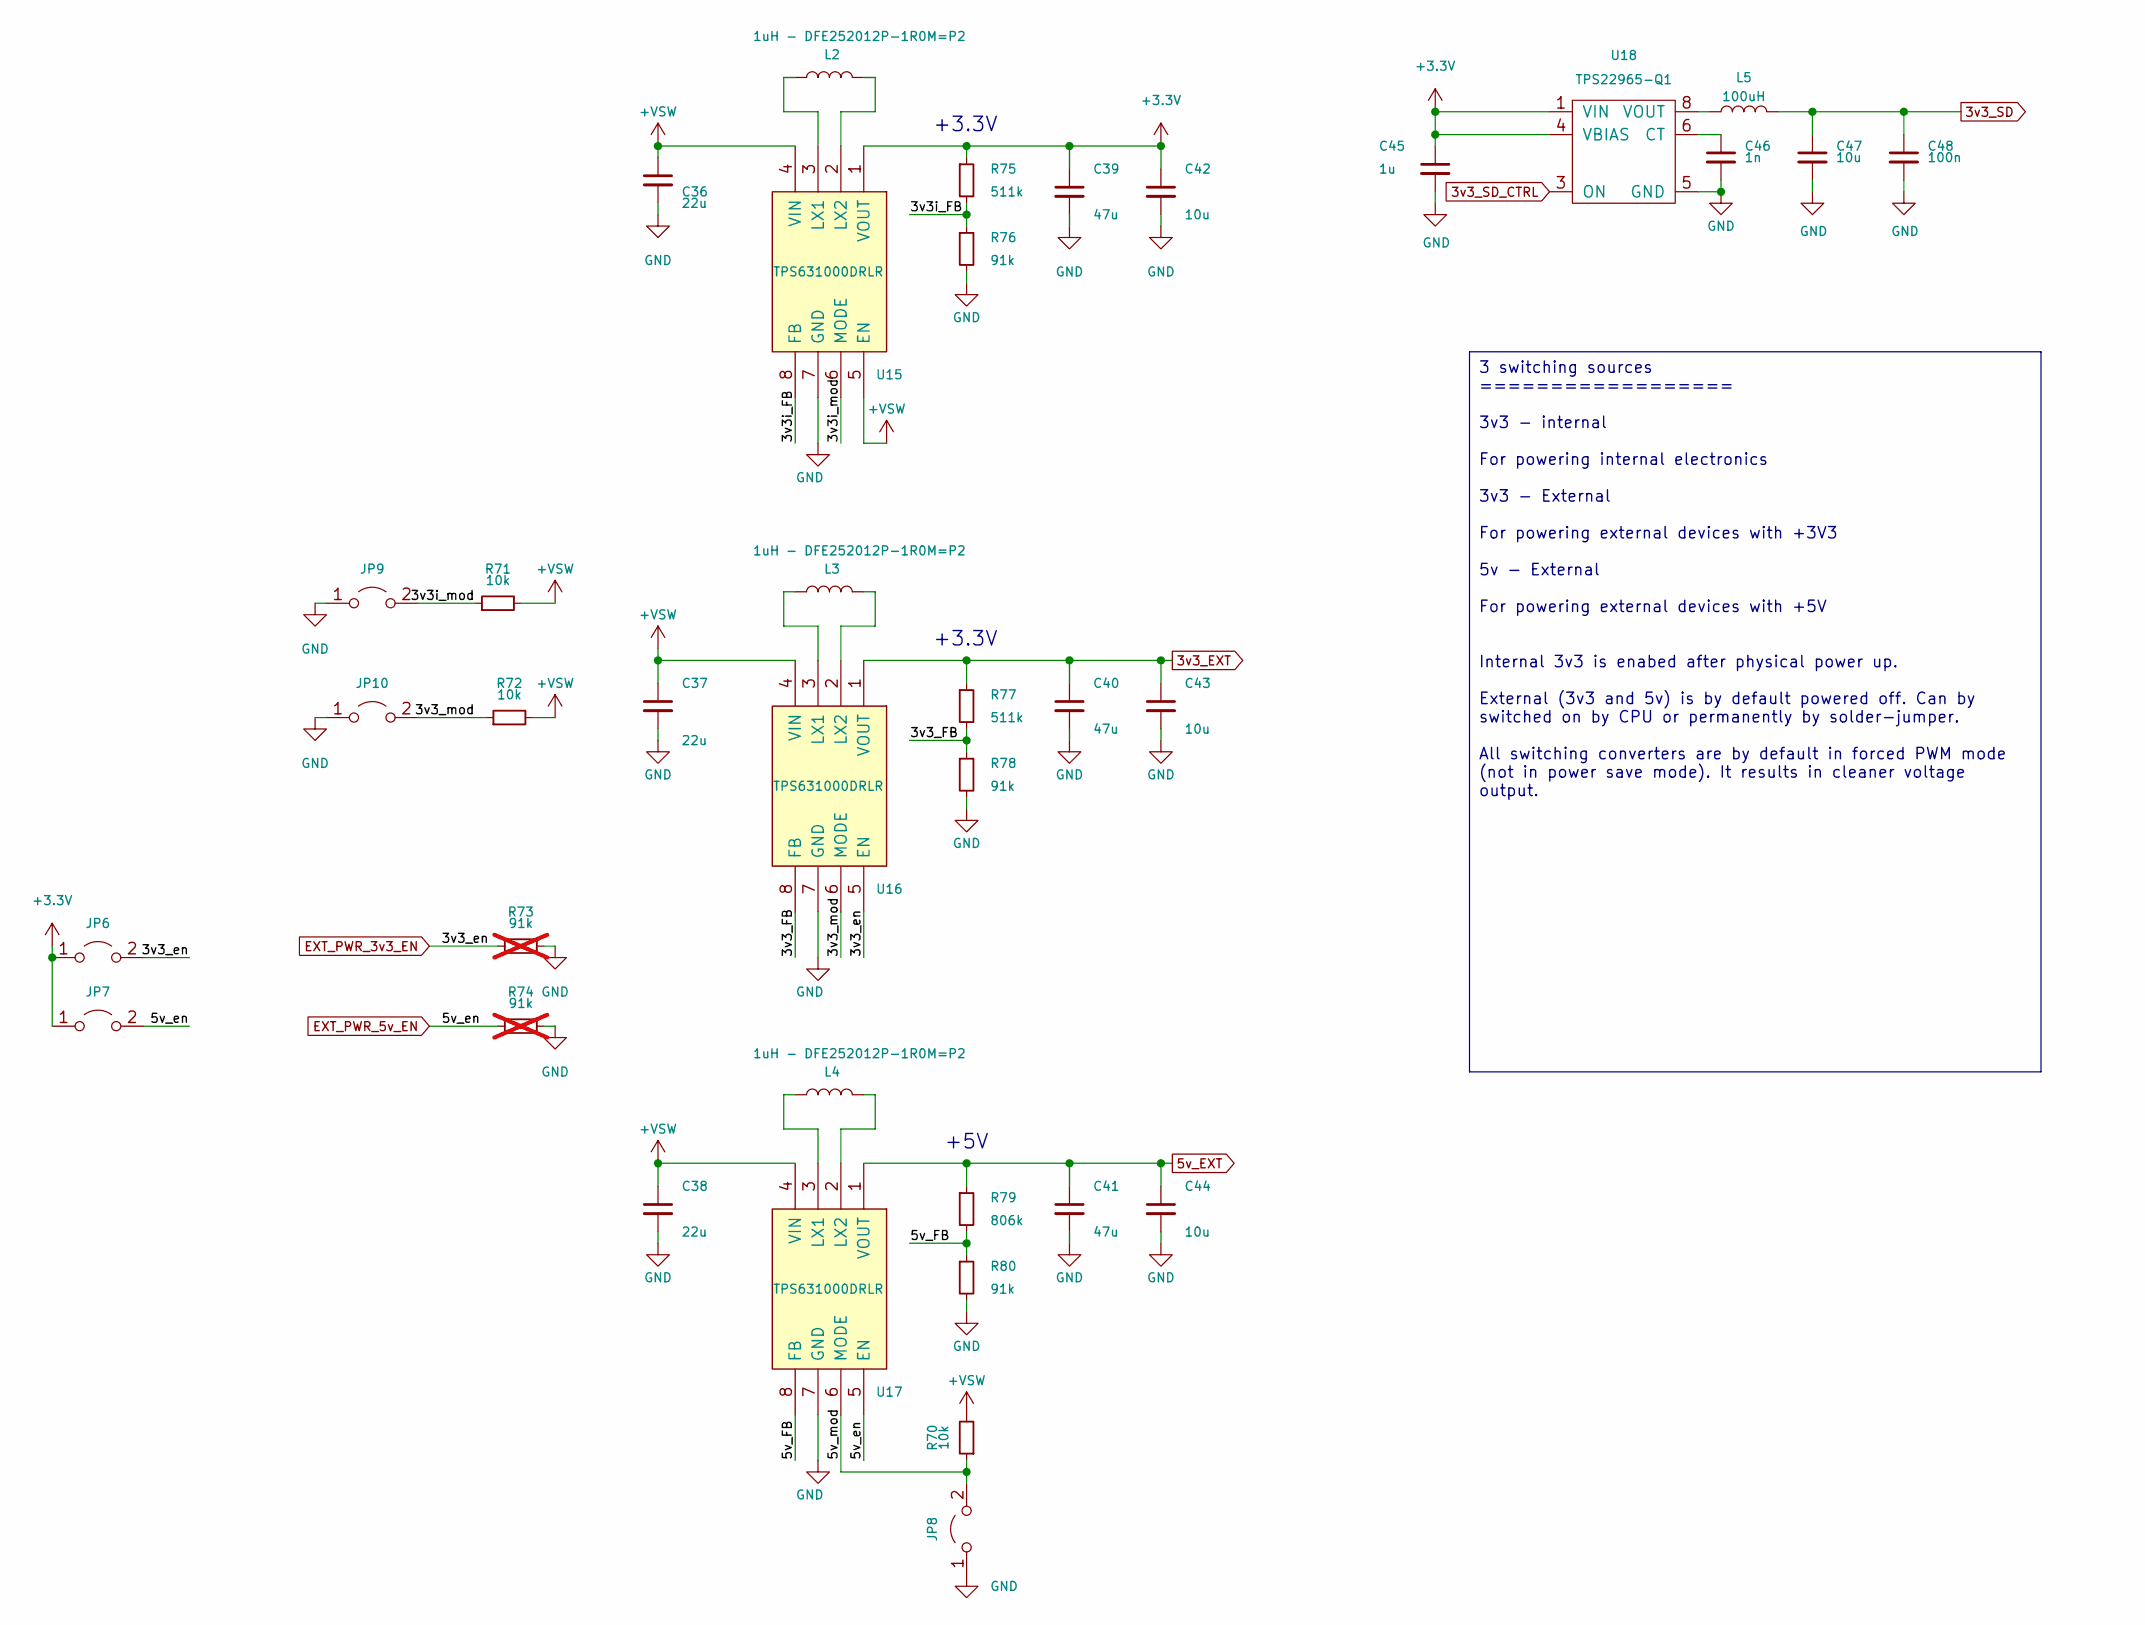
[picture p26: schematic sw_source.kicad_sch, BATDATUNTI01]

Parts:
C36, C37, C38: 22u; C_0805_2012Metric
C39, C40, C41: 47u; C_0805_2012Metric
C42, C43, C44, C47: 10u; C_0805_2012Metric
C45: 1u; C_0805_2012Metric
C46: 1n; C_0805_2012Metric
C48: 100n; C_0805_2012Metric
JP6, JP7, JP8, JP9, JP10: Jumper_2_Open; SolderJumper-2_P1.3mm_Open_RoundedPad1.0x1.5mm
L2, L3, L4: 1uH - DFE252012P-1R0M=P2; L_1008_2520Metric
L5: 100uH; L_0805_2012Metric_Pad1.15x1.40mm_HandSolder
R70, R71, R72: 10k; R_0805_2012Metric
R73, R74: 91k; R_0805_2012Metric; not fitted
R75, R77: 511k; R_0805_2012Metric
R76, R78, R80: 91k; R_0805_2012Metric
R79: 806k; R_0805_2012Metric
U15, U16, U17: TPS631000DRLR; SOT-583-8; Mouser Part Number 595-TPS631000DRLR
U18: TPS22965-Q1; WSON-8-1EP_2x2mm_P0.5mm_EP0.9x1.6mm

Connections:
3v3_EXT: C40.1, C43.1, R77.1, U16.1 (VOUT); also elsewhere on the board
3v3_SD: C47.1, C48.1, L5.2; also elsewhere on the board
3v3_SD_CTRL: U18.3 (ON); also elsewhere on the board
5v_EXT: C41.1, C44.1, R79.1, U17.1 (VOUT); also elsewhere on the board
+3.3V: C39.1, C42.1, C45.1, JP6.1 (A), JP7.1 (A), R75.1, U15.1 (VOUT), U18.1 (VIN), U18.2 (VIN), U18.4 (VBIAS); also elsewhere on the board
+VSW: C36.1, C37.1, C38.1, R70.2, R71.2, R72.2, U15.4 (VIN), U15.5 (EN), U16.4 (VIN), U17.4 (VIN); also elsewhere on the board
/sw_source/3v3_FB: R77.2, R78.1, U16.8 (FB)
/sw_source/3v3_mod: JP10.2 (B), R72.1, U16.6 (MODE)
/sw_source/3v3i_FB: R75.2, R76.1, U15.8 (FB)
/sw_source/3v3i_mod: JP9.2 (B), R71.1, U15.6 (MODE)
/sw_source/5v_FB: R79.2, R80.1, U17.8 (FB)
/sw_source/5v_mod: JP8.2 (B), R70.1, U17.6 (MODE)
EXT_PWR_3v3_EN: JP6.2 (B), R73.2, U16.5 (EN); also elsewhere on the board
EXT_PWR_5v_EN: JP7.2 (B), R74.2, U17.5 (EN); also elsewhere on the board
GND: C36.2, C37.2, C38.2, C39.2, C40.2, C41.2, C42.2, C43.2, C44.2, C45.2, C46.2, C47.2, C48.2, JP8.1 (A), JP9.1 (A), JP10.1 (A), R73.1, R74.1, R76.2, R78.2, R80.2, U15.7 (GND), U16.7 (GND), U17.7 (GND), U18.5 (GND), U18.9; also elsewhere on the board
unnamed: L5.1, U18.7 (VOUT), U18.8 (VOUT)
unnamed: L2.1, U15.3 (LX1)
unnamed: L2.2, U15.2 (LX2)
unnamed: L3.1, U16.3 (LX1)
unnamed: L3.2, U16.2 (LX2)
unnamed: L4.1, U17.3 (LX1)
unnamed: L4.2, U17.2 (LX2)
unnamed: C46.1, U18.6 (CT)

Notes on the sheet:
+3.3V
+5V
3 switching sources ================== 3v3 - internal For powering internal electronics 3v3 - External For powering external devices with +3V3 5v - External For powering external devices with +5V Internal 3v3 is enabed after physical power up. External (3v3 and 5v) is by default powered off. Can by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

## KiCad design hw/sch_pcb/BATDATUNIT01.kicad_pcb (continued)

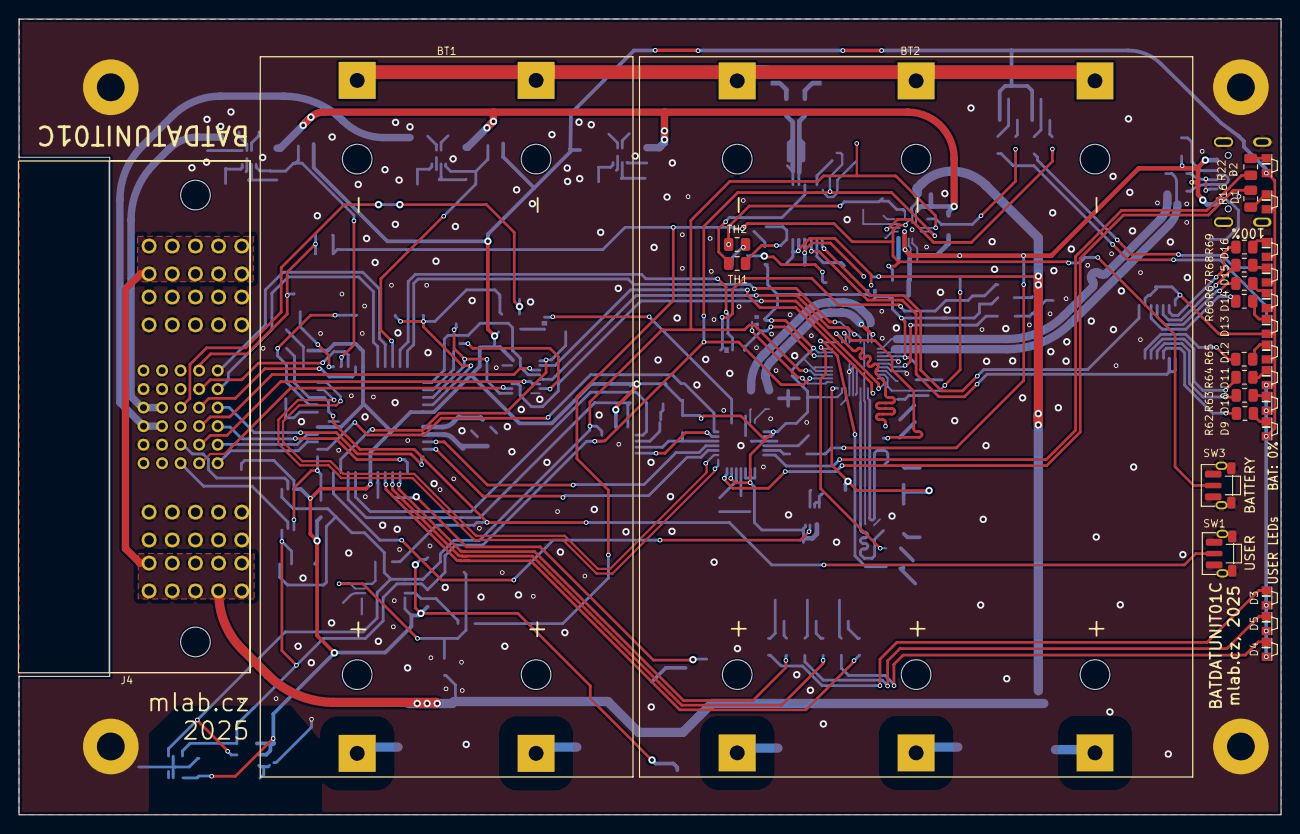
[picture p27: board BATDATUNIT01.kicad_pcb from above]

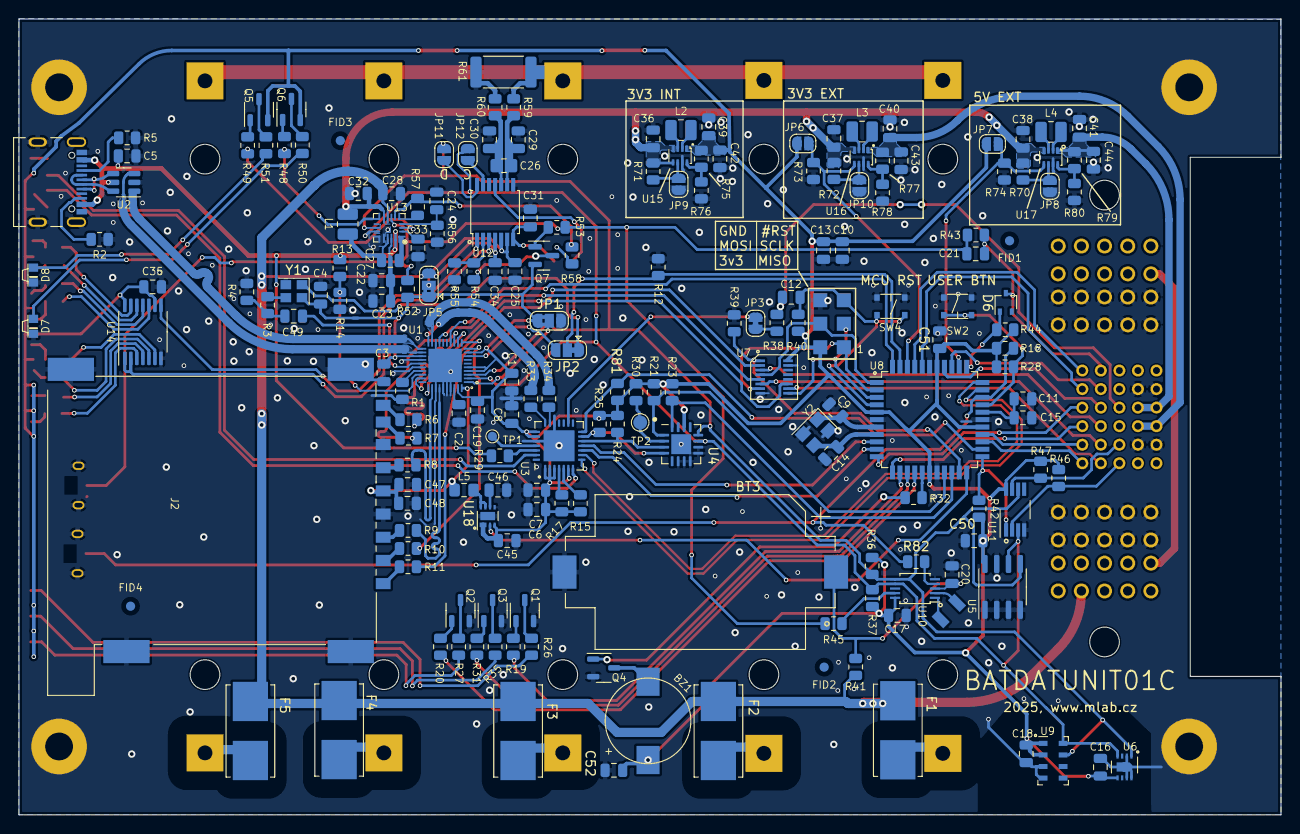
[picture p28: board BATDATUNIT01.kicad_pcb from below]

Board: 2 copper layers, 136.2 x 85.9 mm, 225 parts (191 on the bottom side), 183 nets.

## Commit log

2023-10-18 initial commit, WIP
    [LION5CELL01.kicad_pcb, LION5CELL01.kicad_sch]
2023-10-19 wip: add new components, try to prepare layout outlines
    [LION5CELL01.kicad_pcb, LION5CELL01.kicad_sch, liion.kicad_sch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]
2023-10-20 wip, update schematics, board outlines
    [LION5CELL01.kicad_pcb, LION5CELL01.kicad_sch, liion.kicad_sch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]
2023-10-23 WIP: schematics and layout improvements
    [LION5CELL01.kicad_pcb, LION5CELL01.kicad_sch, connector.kicad_sch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]
2023-10-25 wip layout, add datasheets
    [LION5CELL01.kicad_pcb, LION5CELL01.kicad_sch, connector.kicad_sch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]
2023-10-26 WIP, layout improvement
    [LION5CELL01.kicad_pcb, LION5CELL01.kicad_sch, connector.kicad_sch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]
2023-10-28 wip, layout progress
    [LION5CELL01.kicad_pcb, LION5CELL01.kicad_sch, liion.kicad_sch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]
2023-10-28 wip, layout improvements
    [LION5CELL01.kicad_pcb, LION5CELL01.kicad_sch, liion.kicad_sch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]
2023-10-28 wip: layout
    [LION5CELL01.kicad_pcb]
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2023-11-04 wip, split power adapter to BATDATSOCKET01
    [BATDATUNIT01.kicad_pcb, BATDATUNIT01.kicad_sch, liion.kicad_sch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]
2023-11-05 WIP, add ust ID for existing parts
    [BATDATUNIT01.kicad_pcb, BATDATUNIT01.kicad_sch, connector.kicad_sch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]
2023-11-05 WIP, schematic improvements, bigger page, reststructualized
    [BATDATUNIT01.kicad_pcb, BATDATUNIT01.kicad_sch, liion.kicad_sch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]
2023-11-05 Updates in schematics, improved readability
    [BATDATUNIT01.kicad_pcb, BATDATUNIT01.kicad_sch, liion.kicad_sch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]
2023-11-05 minor updates, update kibot
    [BATDATUNIT01.kicad_sch, liion.kicad_sch, sw_source.kicad_sch]
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2023-11-06 pokus: odebran vykonovy vypinac
    [BATDATUNIT01.kicad_pcb, sw_source.kicad_sch]
2023-11-06 pokus: odstraneni skupin o kterych vim
    [BATDATUNIT01.kicad_pcb, sw_source.kicad_sch]
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2023-11-06 updated power button connection
    [BATDATUNIT01.kicad_pcb, BATDATUNIT01.kicad_sch, liion.kicad_sch]
2023-11-06 allow to keep gauge powered up permanently
    [liion.kicad_sch]
2023-11-06 Layout update, place and route new added components
    [BATDATUNIT01.kicad_pcb, BATDATUNIT01.kicad_sch]
2023-11-06 solve drc, fill ust_id
    [BATDATUNIT01.kicad_pcb, BATDATUNIT01.kicad_sch, liion.kicad_sch]
2023-11-06 update solder jumper to closed
    [BATDATUNIT01.kicad_pcb, BATDATUNIT01.kicad_sch, liion.kicad_sch]
2023-11-07 Add datasheet to RTC schematics symbol.
    [BATDATUNIT01.kicad_sch]
2023-11-07 Connect RTC interrupt pin to charge EXT_DETECTION_CHARGER.
    [BATDATUNIT01.kicad_pcb, BATDATUNIT01.kicad_sch]
2023-11-07 Fix typo in title block.
    [BATDATUNIT01.kicad_sch, liion.kicad_sch, sw_source.kicad_sch]
2023-11-07 tune usb trace length, route RTC wakeup mode
    [BATDATUNIT01.kicad_pcb]
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2023-11-07 Zvetseni mezery od hrany PCB
    [BATDATUNIT01.kicad_pcb]
2023-11-07 Improve layout - Remove copper pour antennas (add grounding vias) - Remove solder mask uncovered traces connections to pads
    [BATDATUNIT01.kicad_pcb, BATDATUNIT01.kicad_sch]
2023-11-07 oprava cesticky u +BATT
    [BATDATUNIT01.kicad_pcb]
2023-11-07 Fix poorly connected vias.
    [BATDATUNIT01.kicad_pcb]
2023-11-07 Resolve ERC errors.
    [BATDATUNIT01.kicad_sch, liion.kicad_sch, sw_source.kicad_sch]
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2023-11-08 Replace absolute 3D model path with relative.
    [BATDATUNIT01.kicad_pcb]
2023-11-14 repair known issues
    [BATDATUNIT01.kicad_pcb, liion.kicad_sch]
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2023-11-18 Fix type of shift register to LEDs.
    [liion.kicad_sch]
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2023-11-19 change I2C switch footprint, change I2C address of MAX IC
    [BATDATUNIT01.kicad_pcb, BATDATUNIT01.kicad_sch]
2023-11-19 Improve readability of schematics.
    [BATDATUNIT01.kicad_sch]
2023-11-19 Fix typos in schematics.
    [BATDATUNIT01.kicad_sch, sw_source.kicad_sch]
2023-11-19 Add vias to improve switching power supply layout.
    [BATDATUNIT01.kicad_pcb]
2023-11-19 Add a link to datasheet to SD card power switch.
    [sw_source.kicad_sch]
2023-11-19 improvements in layout, add oscilator, update mode path, USB line impedance
    [BATDATUNIT01.kicad_pcb, BATDATUNIT01.kicad_sch, liion.kicad_sch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]
2023-11-19 Rework of via placement after incomplete merge.
    [BATDATUNIT01.kicad_pcb]
2023-11-20 minor updates in schematics
    [BATDATUNIT01.kicad_sch, sw_source.kicad_sch]
2023-11-20 Add power consumption notes to schematics.
    [BATDATUNIT01.kicad_sch]
2023-11-26 Vylepseni, upravy layoutu, zmena ovladani ledky, reset pin do molex konektoru
    [BATDATUNIT01.kicad_pcb, BATDATUNIT01.kicad_sch, liion.kicad_sch]
2023-11-27 add USB detect from FTDI to MCU
    [BATDATUNIT01.kicad_pcb, BATDATUNIT01.kicad_sch]
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2023-11-28 Resolve majority of DRC issues.
    [BATDATUNIT01.kicad_pcb, BATDATUNIT01.kicad_sch]
2023-11-28 Change oscillator footprint. WIP
    [BATDATUNIT01.kicad_pcb, BATDATUNIT01.kicad_sch]
2023-11-28 Routed Oscillator in 2.5x2 mm package.
    [BATDATUNIT01.kicad_pcb]
2023-11-28 Add blocking capacitor to EEPROM.
    [BATDATUNIT01.kicad_pcb, BATDATUNIT01.kicad_sch]
2023-11-28 Updata littlefuse footprint to NANO02 fuse holder.
    [BATDATUNIT01.kicad_pcb, liion.kicad_sch]
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2023-11-28 Change USB signal via to uVia.
    [BATDATUNIT01.kicad_pcb]
2023-11-28 Move SD card reader oscillator away from USB data tracks and isolate it by GND strip.
    [BATDATUNIT01.kicad_pcb]
2023-11-28 Swap button pins. Resolve #7
    [BATDATUNIT01.kicad_pcb]
2023-11-28 Fix poor power connection under MCU.
    [BATDATUNIT01.kicad_pcb]
2023-11-28 Connect the RTC time-stamp input to USER A button.
    [BATDATUNIT01.kicad_pcb, BATDATUNIT01.kicad_sch]
2023-11-29 Change diode D6 to decrease leakage current.
    [BATDATUNIT01.kicad_pcb, BATDATUNIT01.kicad_sch]
2023-11-29 Resolve silkscreen overlap.
    [BATDATUNIT01.kicad_pcb]
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2023-12-06 Add note to correct. Orientation of LED bar indicator.
    [liion.kicad_sch]
2023-12-06 Fix LED bar color indication and LED intensity.
    [BATDATUNIT01.kicad_pcb, BATDATUNIT01.kicad_sch, liion.kicad_sch]
2023-12-06 Fix title block and revision.
    [BATDATUNIT01.kicad_pcb]
2023-12-08 add notes to LED currents.
    [BATDATUNIT01.kicad_sch]
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2023-12-10 Update components values to tested ones.
    [BATDATUNIT01.kicad_pcb, BATDATUNIT01.kicad_sch, liion.kicad_sch]
2023-12-10 Fix UST_ID.
    [liion.kicad_sch]
2023-12-10 Update and correct values from manufacturing process.
    [BATDATUNIT01.kicad_pcb, BATDATUNIT01.kicad_sch, liion.kicad_sch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]
2023-12-15 Update the commponent values according to actual component values used during manufacturing.
    [BATDATUNIT01.kicad_pcb, BATDATUNIT01.kicad_sch, liion.kicad_sch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]
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2024-03-29 Update link to buzzer datasheet.
    [BATDATUNIT01.kicad_sch]
2025-04-01 Improve automatic power up reliability by changing power up circuit components values.
    [BATDATUNIT01.kicad_sch, liion.kicad_sch, sw_source.kicad_sch]
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2025-05-10 Convert to KiCAD 9 Add CR2032 battery holder to avoid RTC reset with removed accumulators.
    [BATDATUNIT01.kicad_pcb, BATDATUNIT01.kicad_sch, liion.kicad_sch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]
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2025-05-14 Resolve #11 Improve silkscreen Fix DRC errors.
    [BATDATUNIT01.kicad_pcb]
2025-05-14 Resolve #10 Updating battery holder silkscreen.
    [BATDATUNIT01.kicad_pcb]
2025-05-14 Resolve #8 Mirror symbol vertically in schematic.
    [BATDATUNIT01.kicad_pcb, liion.kicad_sch]
2025-05-14 Resolve #9 Change footprint pads to rectangular.
    [BATDATUNIT01.kicad_pcb]
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2025-05-14 Repair white characters in UST_ID fields.
    [BATDATUNIT01.kicad_pcb, BATDATUNIT01.kicad_sch, sw_source.kicad_sch]
2025-05-14 Fix attributes of some components.
    [BATDATUNIT01.kicad_pcb, BATDATUNIT01.kicad_sch]
2025-09-10 Make schematics more clean.
    [sw_source.kicad_sch]
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
